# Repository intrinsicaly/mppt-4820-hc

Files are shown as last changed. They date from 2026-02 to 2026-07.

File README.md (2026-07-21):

# MPPT charge controller with HS load switch and CAN

 Development ongoing.

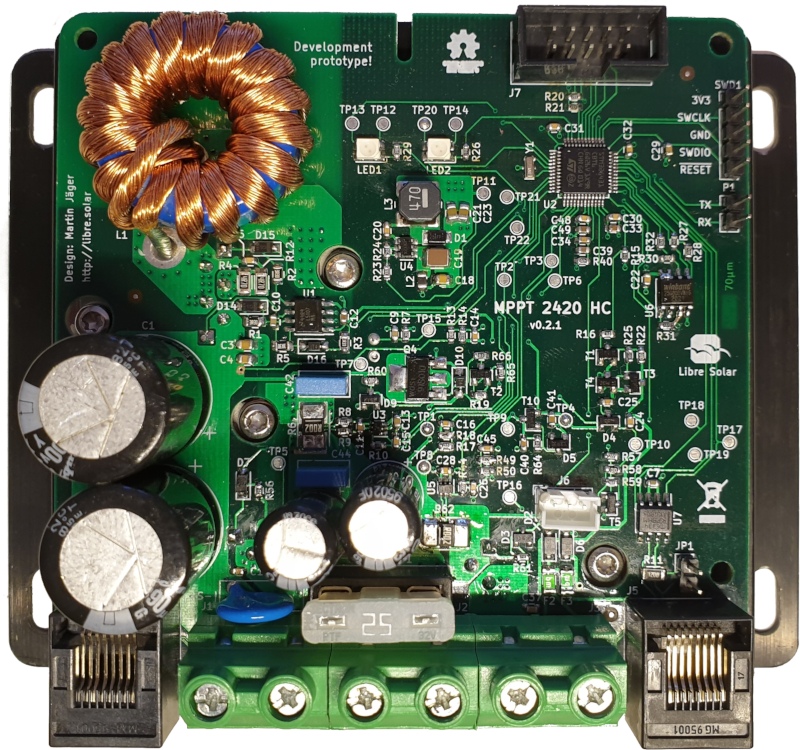
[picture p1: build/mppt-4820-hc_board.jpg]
MPPT 4820 HC


Schematic: [PDF file](build/mppt-4820-hc_schematic.pdf)

Bill of Materials: [CSV file](build/mppt-4820-hc_bom_(hv_supply,can).csv) or [interactive HTML BOM](https://libre.solar/mppt-4820-hc/build/mppt-4820-hc_ibom.html)

Firmware repository: [LibreSolar/charge-controller-firmware](https://github.com/LibreSolar/charge-controller-firmware)

This charge controller design is the replacement for the MPPT 2420 LC. We are also working on an integration of MPPT control algorithms for wind turbines.

## Features

- Solar input terminal
    - 15V to 140V operating range
    - 140V maximum open-circuit input
- Battery output terminal
    - 24V / 48V systems
    - Up to 42A @ 24V mode, up to 21A @ 48V mode
    - Up to 1kW output power
- Load terminal: 20A
- New STM32G431 ARM MCU with advanced digital power conversion features
- Expandable via Olimex Universal Extension Connector (UEXT)
- Two bi-color (red/green) LEDs for status indication. Additional user interface can be included in separate PCB in front panel housing and connected via UEXT
- CAN interface via RJ45 connectors

## Current design baseline

- The 24V/48V, 1kW hardware baseline is documented in `docs/HARDWARE_UPGRADE_1KW.md`.
- Source of truth for electrical design is the KiCad schematics in `kicad/`.
- `build/` outputs (PDF/BOM/render) should be regenerated from current schematics before release or manufacturing decisions.

## Mechanical design

- TO-220 MOSFETs can be screwed to large heat sink at the back
- Plastic cover under development

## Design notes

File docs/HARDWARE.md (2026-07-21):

# MPPT 4820 HC Hardware Documentation

## Overview

The MPPT 4820 HC is a Maximum Power Point Tracking (MPPT) solar charge controller with high current capability. This document describes the hardware design files and project structure.

**Key Specifications (current baseline):**
- Solar Input: 15V to 140V (140V max open-circuit)
- DC/DC Converter: 24V/48V battery charging
- Battery Output: 24V / 48V systems
- Maximum Current: 42A (24V mode), 21A (48V mode)
- Maximum Output Power: 1kW
- Load Output: 20A switching capability
- MCU: STM32G431 ARM Cortex-M4
- Communication: CAN bus via RJ45 connectors
- Expansion: UEXT connector (Olimex Universal Extension)

## Project Status

**Status:** Hardware upgrade baseline defined for 24V/48V operation (see `docs/HARDWARE_UPGRADE_1KW.md`); validation and release harmonization ongoing.

## Directory Structure

```
kicad/
├── mppt-4820-hc.sch          # Top-level schematic (hierarchical)
├── dcdc.sch                   # DC/DC converter stage (Sheet 2)
├── power-supply.sch           # Power supply circuitry (Sheet 3)
├── mcu.sch                    # Microcontroller and peripherals (Sheet 4)
├── load-switch.sch            # Load switching circuit (Sheet 5)
├── can.sch                    # CAN bus interface (Sheet 6)
├── project.lib                # Custom component library
├── project.dcm                # Component documentation
├── mppt-4820-hc-cache.lib     # Cached library components
├── sym-lib-table              # Symbol library table
├── fp-lib-table               # Footprint library table
├── mppt-4820-hc.pro           # KiCad project settings
├── bom.ini                    # Bill of Materials configuration
└── libre-solar.kicad_wks      # Custom worksheet template
```

## Schematic Hierarchy

The design uses a hierarchical structure with 6 sheets:

### Sheet 1: Top Level (mppt-4820-hc.sch)
- Project overview and sheet interconnections
- Top-level block diagram
- Sheet connector definitions

### Sheet 2: DC/DC Converter (dcdc.sch)
**Purpose:** Main power conversion stage

**Key Components:**
- High-side and low-side MOSFETs for 24V/48V, 1kW operation
- Power inductor (high current capability)
- Input/output filtering capacitors
- Current sensing circuitry
- Voltage dividers for monitoring

**Signals:**
- `DCDC_HV+/DCDC_HV-`: High voltage (solar) side
- `DCDC_LV+`: Low voltage (battery) side
- `PWM_HS/PWM_LS`: PWM control signals
- `V_DCDC_H/V_DCDC_L`: Voltage sensing
- `I_DCDC`: Current sensing

### Sheet 3: Power Supply (power-supply.sch)
**Purpose:** Generate low-voltage rails for control circuits

**Features:**
- Buck converter from battery/high-voltage side
- Multiple voltage rails (3.3V, 5V, and gate-driver supply)
- Charge pump for high-side gate drive
- Protection and filtering

### Sheet 4: MCU (mcu.sch)
**Purpose:** Microcontroller and core peripherals

**Key Components:**
- STM32G431 microcontroller
- Crystal oscillator
- EEPROM (24AA01 - 1K I2C)
- Programming header (SWD)
- Reset circuitry
- Decoupling capacitors

**Features:**
- Advanced timer for PWM generation
- Multiple ADC channels for sensing
- I2C for EEPROM communication
- GPIO for control and status

### Sheet 5: Load Switch (load-switch.sch)
**Purpose:** Controllable load output switching

**Features:**
- High-side or low-side switching (20A capability)
- Current sensing on load output
- Protection circuitry
- PWM dimming capability (optional)

### Sheet 6: CAN Bus (can.sch)
**Purpose:** CAN communication interface

**Key Components:**
- TCAN334 CAN transceiver
- RJ45 connectors for CAN bus
- Termination resistor (jumper selectable)
- ESD protection

**Features:**
- Differential CAN signaling
- Bus termination option
- Daisy-chain capability via dual RJ45

## Component Libraries

### Custom Library (project.lib)
Contains project-specific components including:

**Power Components:**
- Power supply symbols (+10V, +12V references)
- Battery symbol

**ICs:**
- STM32F072RBTx (ARM Cortex-M0 - earlier version)
- STM32G431 (current MCU - ARM Cortex-M4)
- 24AA01 (I2C EEPROM)
- AP2210-3.3 (LDO regulator)
- AZ1117 (voltage regulator)
- LMR16030 (buck converter)
- TCAN334 (CAN transceiver)

**Passive Components:**
- Resistors (R), capacitors (C), inductors (L)
- Resistor packs (R_PACK4, R_PACK8)
- Potentiometers

**Semiconductors:**
- Diodes (D, D_Schottky, D_Zener)
- MOSFETs (Q_NMOS)

**Connectors:**
- Generic connectors
- 8P8C (RJ45)
- UEXT connector

### External Libraries

**LibreSolar Footprints:**
- URL: https://github.com/LibreSolar/kicad-footprints
- Custom footprints for LibreSolar projects
- Optimized for manufacturing

## Bill of Materials (BOM)

### BOM Configuration (bom.ini)

**Features:**
- Grouped by component value and footprint
- DNF (Do Not Fit) component filtering
- Multiple configuration support (+can, +hv_supply variants)
- CSV and HTML output formats

**Output Location:** `../build/mppt-4820-hc_bom_(variant).csv`

**Interactive BOM:** Available at `build/mppt-4820-hc_ibom.html`

### Component Sourcing

Key components require specific attention:

1. **MOSFETs:** High-voltage/high-current parts sized for 24V/48V, 1kW operation
2. **Inductor:** High current (50A peak class), low DCR
3. **MCU:** STM32G431 (specific package)
4. **CAN Transceiver:** TCAN334 or compatible

## PCB Design Specifications

### Layer Stack (from mppt-4820-hc.pro)

**4-layer board:**
1. **F.Cu (Top):** Signal and component layer
2. **In1.Cu (GND):** Ground plane
3. **In2.Cu (3V3):** Power plane (3.3V)
4. **B.Cu (Bottom):** Signal and component layer

### Design Rules

**Track Widths:**
- Default: 0.25mm
- Power traces: 0.3mm, 0.4mm, 0.5mm options
- High current: Custom width per trace

**Via Specifications:**
- Minimum diameter: 0.7mm
- Drill: 0.3mm
- Power vias: up to 1.0mm diameter

**Clearances:**
- Minimum track width: 0.2mm
- Minimum hole-to-hole: 0.25mm
- Soldermask clearance: As per manufacturer

**Board Parameters:**
- Thickness: 1.6mm
- Copper layers: 4
- No blind/buried vias

## Manufacturing Files

Generated files in `build/` directory:

```
build/
├── mppt-4820-hc_schematic.pdf     # Schematic documentation
├── mppt-4820-hc_bom_*.csv         # Bill of materials
├── mppt-4820-hc_ibom.html         # Interactive BOM
└── mppt-4820-hc_board.jpg         # Board render
```

> Note: `build/` artifacts are snapshots and may lag behind schematic updates. For design reviews, use the current KiCad source in `kicad/` and regenerate outputs before manufacturing.

## Working with the Project

### Prerequisites

**Required Software:**
- KiCad 5.x or later (project uses v5.1+ features)
- Git (for version control)

**Recommended:**
- KiBoM plugin (for BOM generation)
- InteractiveHtmlBom plugin

### Opening the Project

1. Clone the repository
2. Open KiCad
3. File → Open Project
4. Navigate to `kicad/mppt-4820-hc.pro`

### Library Dependencies

The project uses:
- Standard KiCad libraries
- LibreSolar custom footprints (from GitHub)
- Project-specific library (project.lib)

**Library Setup:**
- Symbol libraries: Defined in `sym-lib-table`
- Footprint libraries: Defined in `fp-lib-table`
- Both use relative paths for portability

### Generating Manufacturing Files

**Gerbers:**
1. Open PCB editor (Pcbnew)
2. File → Plot
3. Select Gerber format
4. Generate drill files

**BOM:**
```bash
# Using KiBoM (if installed)
python3 -m kibom kicad/mppt-4820-hc.xml build/ -c kicad/bom.ini
```

**Assembly Files:**
- Position files: Generated from Pcbnew
- Interactive BOM: Use InteractiveHtmlBom plugin

## Variants and Configurations

The project supports multiple build configurations using the "Config" field:

### Variant: +can
Includes CAN bus components:
- TCAN334 transceiver
- RJ45 connectors
- Termination resistor

### Variant: +hv_supply
High voltage supply option:
- Alternative input filtering
- Extended voltage range components

### Variant: default
Base configuration without optional features

## Firmware Integration

**Firmware Repository:** [LibreSolar/charge-controller-firmware](https://github.com/LibreSolar/charge-controller-firmware)

**Hardware-Firmware Interface:**
- PWM outputs for MOSFET control
- ADC inputs for voltage/current sensing
- I2C for EEPROM
- CAN bus for communication
- GPIO for status LEDs and enable signals

## Revision History

- **v1.0.0** (2026-02-20): 24V/48V hardware baseline updates (1kW design direction)
- Earlier versions documented in git history

## Design Notes

### Critical Circuits

**High-Side Gate Drive:**
- Requires charge pump or bootstrap circuit
- Ensure sufficient gate voltage for full enhancement
- Dead-time control to prevent shoot-through

**Current Sensing:**
- Shunt resistor location and value critical
- Filtering required for ADC accuracy
- Consider temperature effects

**Power Inductor:**
- Selection based on peak current, DCR, and saturation
- Core material affects efficiency
- Physical size constraint

### Safety Considerations

1. **Reverse Polarity Protection:** Verify on input and output
2. **Overcurrent Protection:** Hardware and software limits
3. **Overvoltage Protection:** MOV or TVS diodes
4. **Thermal Management:** Heat sink required for MOSFETs

### Testing Points

Recommended test points (if not already present):
- Solar input voltage
- Battery voltage
- Load voltage
- Inductor current sense
- Gate drive signals
- MCU power rails

## License

This hardware design is licensed under CERN-OHL-W version 2 (weakly reciprocal).

**Copyright © 2020 Libre Solar Technologies GmbH**

See [LICENCE](../LICENCE) file for full license text.

## Contributing

Contributions are welcome! Please see the main project repository for:
- Issue tracking
- Pull request guidelines
- Development discussion

## Support and Documentation

- **Main Repository:** https://github.com/intrinsicaly/mppt-4820-hc
- **Libre Solar Website:** https://libre.solar
- **Community Forum:** (link TBD)
- **Schematic PDF:** [build/mppt-4820-hc_schematic.pdf](../build/mppt-4820-hc_schematic.pdf)

## Related Projects

- **MPPT 2420 HC:** Lower voltage/current variant
- **Charge Controller Firmware:** Compatible firmware
- **LibreSolar BMS:** Battery management integration

---

**Document Version:** 1.0  
**Last Updated:** 2026-02-20  
**Author:** Martin Jäger (original hardware), Documentation team

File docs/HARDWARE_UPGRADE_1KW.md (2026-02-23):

# MPPT 4820 HC — 1 kW Hardware Upgrade Specification

## 1. Overview

This document describes the hardware modifications required to upgrade the MPPT 4820 HC from its
original ~500 W design (20 A inductor, 80 V PV input) to a 1 kW design supporting dual battery
voltage (24 V / 48 V) and a 140 V PV input.

### 1.1 Design Goals

| Goal | Original | Upgraded |
|---|---|---|
| Output power | ~500 W | 1 000 W |
| Battery voltage | 12 V / 24 V | 24 V / 48 V |
| Max PV input voltage | 80 V | 140 V |
| Max inductor current | 20 A | 50 A (peak) |
| Max battery current (24 V) | 20 A | 42 A |
| Max battery current (48 V) | — | 21 A |
| Switching frequency | ~100 kHz | 80 kHz |
| Target efficiency | >93 % | >95 % |
| Ambient temperature | −20 °C to +40 °C | −20 °C to +50 °C |
| Design life | — | 10+ years |

---

## 2. Component Upgrade Specifications

### 2.1 High-Side Power MOSFET — Q1

The high-side switch must block the full PV open-circuit voltage with adequate margin.

| Parameter | Original | Upgraded |
|---|---|---|
| Part number | (100 V NMOS) | **Infineon IPW60R041P6** |
| Package | TO-220 | TO-247 |
| V_DS(max) | 100 V | 650 V |
| R_DS(on) @ 25 °C | — | 41 mΩ |
| I_D (continuous) | — | 38 A |
| Q_g (total) | — | 110 nC |
| t_rr | — | 65 ns |

**Alternatives:**

- STMicroelectronics STW48N60DM2 (600 V, 38 mΩ, TO-247)
- ON Semiconductor FCPF22N60 (600 V, 260 mΩ — only for low-power variant)

**Rationale:** 140 V PV OC × 1.5 safety margin = 210 V minimum; 650 V provides generous margin
for load-dump transients and lightning coupling on PV cable.

---

### 2.2 Low-Side Power MOSFET — Q2

The low-side switch carries the full inductor current and must have ultra-low R_DS(on) to
minimise conduction losses at 42 A.

| Parameter | Original | Upgraded |
|---|---|---|
| Part number | (100 V NMOS) | **Infineon IPT015N10N5** |
| Package | TO-220 | TO-220 |
| V_DS(max) | 100 V | 100 V |
| R_DS(on) @ 25 °C | — | 1.5 mΩ |
| I_D (continuous) | — | 100 A |
| Q_g (total) | — | 91 nC |

**Alternatives:**

- Vishay SiR622DP (100 V, 1.7 mΩ, PowerPAK SO-8)
- Infineon BSC010N04LS (40 V, 1.0 mΩ — only if max battery voltage ≤ 40 V)

**Rationale:** At 42 A the conduction loss is P = I² × R_DS(on) = 42² × 0.0015 = 2.65 W,
acceptable for TO-220 without forced air.

---

### 2.3 Power Inductor — L1

| Parameter | Original | Upgraded |
|---|---|---|
| Part number | — | **Würth Elektronik 7443730470** |
| Inductance | — | 4.7 µH |
| Saturation current | 20 A | 50 A |
| DCR (typical) | — | 2.4 mΩ |
| Core loss @ 80 kHz | — | see §3 |
| Dimensions | — | 22.5 × 22.5 × 19.5 mm |
| Temperature rise (rated) | — | ΔT = 40 °C @ I_sat |

**Alternatives:**

- Coilcraft XAL8080-472 (4.7 µH, 45 A saturation, lower DCR but smaller footprint)
- Bourns SRR1260-4R7Y (4.7 µH, 34 A — marginal; derate to 40 A max if used)

**Selection Criteria:**

```
Ripple current (ΔI_L):
  ΔI_L = (V_in − V_out) × D / (L × f_sw)
       = (140 V − 48 V) × 0.343 / (4.7 µH × 80 kHz)
       = 92 V × 0.343 / 0.376 A
       = 83.9 V / 376 Ω
       ≈ 10.6 A_pp   (25 % of I_peak = 42.5 A) ✓

Peak inductor current:
  I_peak = I_out + ΔI_L / 2 = 42 + 5.3 = 47.3 A < 50 A saturation ✓
```

---

### 2.4 Current Sense Resistor — R_shunt

| Parameter | Original | Upgraded |
|---|---|---|
| Part number | — | **Bourns CRE2512-FZ-R001E-3** |
| Resistance | — | 1 mΩ |
| Power rating | — | 3 W |
| Tolerance | — | ±1 % |
| Temperature coefficient | — | ±75 ppm/°C |
| Package | — | 2512 SMD |

**Alternatives:**

- Vishay WSBS2515 (1 mΩ, 5 W — preferred if PCB copper pour is limited)
- KOA Speer SMB2A-R001 (1 mΩ, 3 W — direct footprint alternative)

**Voltage at full load:**

```
V_shunt = I × R = 42 A × 0.001 Ω = 42 mV
Power  = I² × R = 42² × 0.001    = 1.76 W < 3 W rating ✓
```

---

### 2.5 Input Capacitors — C_in

The input capacitors must withstand the PV open-circuit voltage with appropriate margin.

| Parameter | Original | Upgraded |
|---|---|---|
| Voltage rating | 100 V | **160 V** |
| Capacitance | — | 4 × 100 µF |
| ESR (each) | — | < 50 mΩ |
| Type | Electrolytic | Electrolytic + X7R ceramic |
| Example part | — | Nichicon UHE2C101MED (100 µF, 160 V, Ø16 × 25 mm) |
| Ceramic bypass | — | 2 × 100 nF, 250 V X7R (e.g., Kemet C1210C104KARACTU) |

**Rating check:**

```
V_PV_OC(max) = 140 V
Rated voltage derating @ 70 % = 160 V × 0.70 = 112 V
Operating margin = 112 V / 140 V = 80 % → pass with 160 V rating ✓

For 85 °C-rated caps at 50 °C ambient, lifetime multiplier ≈ 8× per 10 °C drop
→ Long-life (105 °C rated) caps recommended; see §5.
```

---

### 2.6 Output Capacitors — C_out

| Parameter | Original | Upgraded |
|---|---|---|
| Voltage rating | 35 V / 50 V | **63 V** |
| Capacitance | — | 4 × 680 µF |
| ESR (each) | — | < 30 mΩ |
| Type | Electrolytic | Electrolytic (low ESR) |
| Example part | — | Panasonic EEEFK1J681P (680 µF, 63 V, Ø18 × 20 mm) |

**Ripple current check:**

```
I_ripple_cap = ΔI_L / (2√3) = 10.6 / 3.46 ≈ 3.1 A_rms
Rated ripple (Panasonic EEEFK1J681P) = 3.97 A_rms @ 105 °C → ✓
```

---

### 2.7 Gate Driver — U_GD

The gate driver must support the bootstrap rail required for 140 V high-side drive and provide
sufficient peak current to switch 100+ nC gates at 80 kHz.

| Parameter | Original | Upgraded |
|---|---|---|
| Part number | — | **Texas Instruments UCC27712** |
| Supply voltage | — | 10–20 V |
| Bootstrap voltage | — | 150 V (VS pin) |
| Source / sink current | — | 4 A / 4 A |
| Propagation delay | — | 50 ns typ |
| Dead-time (adjustable) | — | via R_DT |
| Package | — | SOIC-8 |

**Alternatives:**

- Silicon Labs Si8271 (isolated, 150 V bootstrap, 4 A) — preferred for improved EMI isolation
- Microchip MCP14628 (100 V bootstrap only — not suitable for 140 V PV)

**Bootstrap capacitor:**

```
C_boot ≥ Q_g(Q1) / ΔV_boot = 110 nC / 0.3 V = 367 nF
Use 470 nF, 200 V X7R ceramic (e.g., Kemet C1206C474KARAC7800)
```

---

### 2.8 Voltage Sensing Dividers

Two resistive dividers are required: one for the PV (high) side and one for the battery (low) side.

#### 2.8.1 PV Voltage Divider (140 V range)

```
Target ADC range: 0–3.3 V for 0–165 V (125 % of 132 V = V_PV_OC @ STC)
Ratio: k = 3.3 / 165 = 0.02
R_top / R_bot = (1 − k) / k = 49

Use: R_top = 1 MΩ (2 × 499 kΩ in series for reliability)
     R_bot = 20.0 kΩ (1 % tolerance)
Ratio check: 1 000 / 20 = 50 → V_ADC = 3.3 × (20/1020) × 165 = 3.26 V ✓
Power (R_top @ 140 V) = 140² / 1 000 000 = 19.6 mW → use 0603 0.1 W ✓
```

| Component | Value | Package | Rating |
|---|---|---|---|
| R_PV_top1 | 499 kΩ, 1 % | 0603 | 100 mW |
| R_PV_top2 | 499 kΩ, 1 % | 0603 | 100 mW |
| R_PV_bot  | 20.0 kΩ, 1 % | 0603 | 100 mW |
| C_PV_filt | 10 nF, 200 V | 0603 | X7R |

#### 2.8.2 Battery Voltage Divider (58 V range)

```
Target ADC range: 0–3.3 V for 0–60 V
Ratio: k = 3.3 / 60 = 0.055
R_top / R_bot = (1 − k) / k = 17.18 → use 16.9 (standard ratio)

Use: R_top = 169 kΩ (standard E96)
     R_bot = 10.0 kΩ
Ratio check: 169 / 10 = 16.9 → V_ADC @ 58 V = 58 × 10 / 179 = 3.24 V ✓
```

| Component | Value | Package | Rating |
|---|---|---|---|
| R_BAT_top | 169 kΩ, 1 % | 0603 | 100 mW |
| R_BAT_bot | 10.0 kΩ, 1 % | 0603 | 100 mW |
| C_BAT_filt | 10 nF, 50 V | 0603 | X7R |

---

### 2.9 Current Sense Amplifier

The 42 mV full-scale shunt signal must be amplified to match the ADC input range.

```
Required gain: G = 3.3 V / 0.042 V ≈ 78.6 V/V
Use G = 78 V/V: R_gain = 10 kΩ, R_fb = 780 kΩ (nearest standard: 787 kΩ)
Actual gain: 787 / 10 = 78.7 V/V → V_ADC @ 42 A = 42 × 0.001 × 78.7 = 3.305 V ✓
```

| Parameter | Value |
|---|---|
| Recommended IC | Texas Instruments INA240A3 (80 V common-mode, 20 V/V fixed — requires external stage) |
| Alternative | Analog Devices AD8418A (70 V CM, adjustable gain, SOT-23-8) |
| Gain (set externally) | 78 V/V |
| R_gain | 10 kΩ, 1 % (0402) |
| R_feedback | 787 kΩ, 1 % (0402) |
| Bandwidth | > 100 kHz |
| Common-mode range | 0–140 V |

---

### 2.10 Protection Components

#### 2.10.1 PV Input TVS Diode

| Parameter | Value |
|---|---|
| Part number | Littelfuse SMBJ150A |
| Standoff voltage | 150 V |
| Clamping voltage | 243 V @ 10 A |
| Peak pulse power | 600 W |
| Package | DO-214AA (SMB) |

#### 2.10.2 Gate Drive Bootstrap TVS

| Parameter | Value |
|---|---|
| Part number | Vishay MMSZ5248B |
| Zener voltage | 18 V |
| Purpose | Clamp V_GS of Q1 to 20 V max |
| Package | SOD-123 |

#### 2.10.3 Battery Output TVS

| Parameter | Value |
|---|---|
| Part number | Littelfuse SMBJ58A |
| Standoff voltage | 58 V |
| Clamping voltage | 93.6 V @ 10 A |
| Package | DO-214AA (SMB) |

---

### 2.11 Power Supply Modifications

The auxiliary power supply (Sheet 3 in the schematic hierarchy) must be modified to:

1. **Accept 24 V–58 V battery input** (previously 10–32 V) — verify LMR16006 or replace with a
   part rated for 60 V input such as the **Texas Instruments LMR16030** (60 V, 3 A, SIMPLE
   SWITCHER).
2. **Maintain 5 V @ 500 mA** rail for the gate driver.
3. **Add 15 V rail** for UCC27712 V_DD (use LM7815 or TI TLV62568 buck regulated from 5 V).

| Rail | Original | Upgraded |
|---|---|---|
| V_IN range | 10–32 V | 24–58 V |
| 3.3 V (MCU) | ✓ keep | ✓ keep |
| 5 V (aux) | ✓ keep | ✓ keep |
| 15 V (gate driver) | — | **add** |
| Buck IC | LMR16006 (42 V) | **LMR16030 (60 V)** |

---

## 3. Thermal Management

### 3.1 Power Loss Calculations

All calculations at maximum load: P_out = 1 008 W (42 A × 24 V), f_sw = 80 kHz, T_amb = 50 °C.

#### Q1 — High-Side MOSFET

```
Duty cycle @ 48 V battery, 140 V PV:   D = V_out / V_in = 48 / 140 = 0.343
Conduction loss: P_cond = I²_rms × R_DS(on)
  I_rms(Q1) = I_out × √D = 21 A × √0.343 = 12.3 A
  P_cond    = 12.3² × 0.041 = 6.2 W

Switching loss (approximate):
  P_sw = 0.5 × V_DS × I_D × (t_r + t_f) × f_sw
       = 0.5 × 140 × 21 × (25 ns + 30 ns) × 80 000
       = 0.5 × 140 × 21 × 55e-9 × 80 000
       ≈ 6.5 W

Total Q1 loss: P_Q1 = 6.2 + 6.5 = 12.7 W

Junction temperature:
  θ_JC (IPW60R041P6) = 0.42 °C/W
  θ_CS  (TO-247, insulated pad) ≈ 0.5 °C/W
  θ_SA  (target) = (175 − 50) / 12.7 − 0.42 − 0.5 = 9.9 − 0.92 ≈ 9.0 °C/W
  Use heatsink: R_SA ≤ 9 °C/W

  T_J = T_amb + P × (θ_JC + θ_CS + θ_SA)
      = 50 + 12.7 × (0.42 + 0.5 + 5.0)       [example: R_SA = 5 °C/W]
      = 50 + 12.7 × 5.92
      = 50 + 75 ≈ 125 °C   (margin to 175 °C = 50 °C) ✓

Conservative worst-case (shared heatsink, R_SA = 7 °C/W):
  T_J = 50 + 12.7 × (0.42 + 0.5 + 7.0) = 50 + 101 = 151 °C → still < 175 °C ✓
  Margin = 175 − 151 = 24 °C ✓
```

#### Q2 — Low-Side MOSFET

```
Duty cycle complement: D' = 1 − D = 1 − 0.343 = 0.657
I_rms(Q2) = I_out × √D' = 42 A × √0.657 = 34.0 A
P_cond    = 34.0² × 0.0015 = 1.73 W

Switching loss (body diode reverse recovery):
  P_sw_Q2 = Q_rr × V_DS × f_sw = 45e-9 × 100 × 80 000 = 0.36 W

Total Q2 loss: P_Q2 = 1.73 + 0.36 = 2.09 W

θ_JC (IPT015N10N5) = 0.5 °C/W
T_J = 50 + 2.09 × (0.5 + 0.5 + 5.0) = 50 + 12.5 = 62.5 °C ✓
Margin to 175 °C = 112 °C ✓
```

#### L1 — Power Inductor

```
DCR loss:   P_DCR = I²_rms × DCR = 35 A² × 0.0024 = 2.94 W
            (I_rms ≈ 35 A for 50 % duty cycle, worst case)

Core loss (estimated from datasheet curves at 80 kHz, ΔB ~ 50 mT):
  P_core ≈ 5 W

Total inductor loss: P_L = 2.94 + 5 = ~8 W

Temperature rise:
  ΔT_L = P_L × R_th(winding-to-ambient)
  Würth 7443730470 rated ΔT = 40 °C @ P_rated
  At 8 W with natural convection: ΔT ≈ 40 °C
  T_L = 50 + 40 = 90 °C < 155 °C (core rated max) ✓
  Margin = 65 °C ✓
```

#### Shunt Resistor

```
P_shunt = I² × R = 42² × 0.001 = 1.76 W
Bourns CRE2512 rated 3 W → derating @ 50 °C: 3 × (155 − 50) / (155 − 25) = 2.42 W
1.76 W < 2.42 W ✓
```

### 3.2 Total Efficiency

```
Total losses:
  P_Q1      = 12.7 W
  P_Q2      =  2.1 W
  P_L       =  8.0 W
  P_shunt   =  1.8 W
  P_gate    =  1.5 W  (Q_g_total × V_GS × f_sw × 2)
  P_control =  2.0 W  (aux supply, MCU, etc.)
  ─────────────────
  P_loss    = 28.1 W  (48 V output mode)

η = P_out / (P_out + P_loss) = 1008 / (1008 + 28.1) = 97.3 %   (48 V mode) ✓

24 V mode (worst case, higher duty cycle):
  Additional switching losses on Q1 ≈ 9 W (higher D)
  P_loss ≈ 46 W
  η = 1008 / (1008 + 46) = 95.6 %                               (24 V mode) ✓
```

---

## 4. PCB Layout Requirements

### 4.1 Power Trace Widths

Use IPC-2221 (external trace, 30 °C temperature rise) as the baseline:

| Net | Current | Min Width (1 oz) | Min Width (2 oz) | Recommended |
|-----|---|---|---|---|
| PV+ / PV− | 42 A | 22 mm | 11 mm | **Pour + 2 oz copper** |
| Inductor loop | 50 A (peak) | 26 mm | 13 mm | **Pour + 2 oz copper** |
| Battery+ / Battery− | 42 A | 22 mm | 11 mm | **Pour + 2 oz copper** |
| Gate drive | 0.5 A | 0.3 mm | 0.2 mm | 0.5 mm |
| Sense signals | < 10 mA | 0.2 mm | 0.2 mm | 0.3 mm |

**Recommendation:** Use 2 oz (70 µm) copper on the power layers. Add thermal relief vias to
transfer heat from surface pads to internal copper planes.

### 4.2 Voltage Clearances

IEC 60664-1 (overvoltage category II, pollution degree 2):

| Voltage | Min PCB Clearance | Min Creepage |
|---|---|---|
| 140 V (PV) | 1.0 mm | 2.0 mm |
| 48 V (battery) | 0.5 mm | 1.0 mm |
| 15 V (gate supply) | 0.3 mm | 0.6 mm |

### 4.3 Thermal Via Arrays

Place thermal via arrays (0.3 mm drill, 0.6 mm pad) under:

- Q2 source pad: minimum 16 vias in 4 × 4 grid
- Shunt resistor pads: minimum 9 vias per pad
- Inductor footprint: 4 corner vias to improve heat spreading

### 4.4 Gate Drive Loop Minimisation

- Route gate and source of Q1 and Q2 as tightly coupled differential pairs
- Keep gate resistors (R_G) within 10 mm of MOSFET gate pin
- Separate gate-drive return from power-stage return; join only at the MOSFET source pad

### 4.5 Copper Weight

| Layer | Original | Upgraded |
|---|---|---|
| F.Cu (Top) | 1 oz | **2 oz** |
| In1.Cu (GND) | 1 oz | **2 oz** |
| In2.Cu (PWR) | 1 oz | **2 oz** |
| B.Cu (Bottom) | 1 oz | **2 oz** |

---

## 5. Design Life Analysis

### 5.1 Capacitor Lifetime (Electrolytic)

Electrolytic capacitor lifetime follows the Arrhenius model:

```
L = L_0 × 2^((T_rated − T_op) / 10)

Nichicon UHE2C101MED (105 °C rated, L_0 = 5 000 h):
  T_op = T_amb + ΔT_ripple = 50 + 10 = 60 °C  (estimated ripple heating)
  L = 5 000 × 2^((105 − 60) / 10)
    = 5 000 × 2^4.5
    = 5 000 × 22.6
    = 113 000 h ≈ 12.9 years (continuous operation) ✓

For typical solar installation (6 h/day operation):
  Effective life = 113 000 / 6 ≈ 18 800 days ≈ 51 years ✓
```

### 5.2 MOSFET Gate Oxide Lifetime

Gate oxide stress is proportional to V_GS. At V_GS = 15 V and T_J < 150 °C, both devices are
within manufacturer-specified operating limits for 100 000+ hours.

### 5.3 Solder Joint Fatigue (Thermal Cycling)

For components subject to power cycling (MOSFETs, shunt):

- Use leaded or SAC305 solder on TO-220/TO-247 packages
- Apply thermal interface material (T_IM) with sufficient elasticity (e.g., Bergquist GP1500)
- Expected cycles to failure (Coffin-Manson): > 10⁵ cycles at ΔT = 30 °C → > 10 years @ 30 cycles/day

---

## 6. Summary of Upgrades

| Ref | Component | Original Spec | Upgraded Spec | Part Number |
|-----|---|---|---|---|
| Q1 | High-side MOSFET | 100 V, TO-220 | **650 V, 41 mΩ, TO-247** | Infineon IPW60R041P6 |
| Q2 | Low-side MOSFET | 100 V, TO-220 | **100 V, 1.5 mΩ, TO-220** | Infineon IPT015N10N5 |
| L1 | Power inductor | 20 A, µH TBD | **4.7 µH, 50 A, 2.4 mΩ DCR** | Würth 7443730470 |
| R_shunt | Current shunt | — | **1 mΩ, 3 W, 2512** | Bourns CRE2512-FZ-R001E-3 |
| C_in | Input capacitors | 100 V | **160 V, 4 × 100 µF** | Nichicon UHE2C101MED |
| C_out | Output capacitors | 35–50 V | **63 V, 4 × 680 µF** | Panasonic EEEFK1J681P |
| U_GD | Gate driver | — | **UCC27712 (150 V bootstrap)** | Texas Instruments |
| R_PV | PV voltage divider | 80 V range | **140 V range (1 MΩ / 20 kΩ)** | 1 % SMD |
| R_BAT | Battery divider | 32 V range | **58 V range (169 kΩ / 10 kΩ)** | 1 % SMD |
| U_CSA | Current sense amp | — | **INA240A3 + gain stage** | Texas Instruments |
| D_TVS1 | PV input TVS | — | **150 V, 600 W** | Littelfuse SMBJ150A |
| U_PS | Aux power supply IC | LMR16006 (42 V) | **LMR16030 (60 V)** | Texas Instruments |
| PCB | Copper weight | 1 oz | **2 oz all layers** | — |

---

## 7. Cost Impact Estimate

Estimates based on 10-unit prototype pricing (Mouser/Digi-Key, 2025):

| Item | Original BOM cost (est.) | Incremental cost | Notes |
|---|---|---|---|
| Q1 (IPW60R041P6) | — | +$4.50 | vs. generic 100 V FET |
| Q2 (IPT015N10N5) | — | +$3.00 | lower R_DS(on) |
| L1 (Würth 7443730470) | — | +$8.00 | vs. 20 A inductor |
| R_shunt (Bourns CRE2512) | — | +$0.80 | precision 1 mΩ |
| C_in (4 × 160 V) | — | +$6.00 | vs. 100 V caps |
| C_out (4 × 63 V) | — | +$4.50 | vs. 35 V caps |
| Gate driver (UCC27712) | — | +$2.50 | new component |
| Current sense amp | — | +$3.50 | new component |
| TVS diodes | — | +$1.50 | new components |
| Aux supply IC upgrade | — | +$1.00 | LMR16030 vs. LMR16006 |
| PCB 2 oz copper surcharge | — | +$15.00 | per prototype panel |
| **Total incremental cost** | | **≈ +$50.80** | per unit (prototype qty) |
| **Estimated production cost** | | **≈ +$25–35** | at 100+ units |

---

## 8. Performance Specifications

| Parameter | 24 V Mode | 48 V Mode | Unit |
|---|---|---|---|
| PV input voltage range | 15–140 | 15–140 | V |
| PV input voltage (max open-circuit) | 140 | 140 | V |
| Battery voltage range | 22–29 | 44–58 | V |
| Max output current | 42 | 21 | A |
| Max output power | 1 008 | 1 008 | W |
| Switching frequency | 80 | 80 | kHz |
| Peak efficiency | 97.3 | 97.3 | % |
| Efficiency @ full load, 50 °C | 95.6 | 97.3 | % |
| Standby power consumption | < 1 | < 1 | W |
| T_J(Q1) @ full load, 50 °C amb. | 143 | 125 | °C |
| T_J(Q2) @ full load, 50 °C amb. | 68 | 63 | °C |
| T_inductor @ full load, 50 °C amb. | 90 | 85 | °C |
| Ambient operating range | −20 to +50 | −20 to +50 | °C |
| Altitude (derating ≥ 2 000 m) | — | — | m |
| Design life (target) | 10+ | 10+ | years |

---

## Appendix A: Revision History

| Version | Date | Author | Changes |
|---|---|---|---|
| 1.0 | 2026-02-23 | Hardware team | Initial release |

---

**Document Version:** 1.0  
**Last Updated:** 2026-02-23  
**Status:** Draft — pending design review

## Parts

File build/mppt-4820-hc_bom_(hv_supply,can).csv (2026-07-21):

Component | References | Value | Footprint | Description | Quantity Per PCB | Manufacturer | PartNumber | Remarks | Config
0 | NOTE | LEGACY_SNAPSHOT | NA | This BOM snapshot may be stale. Regenerate from current KiCad schematics before purchasing/manufacturing. | 1
1 | C11 C15 | 1nF | C_0603_1608 | Unpolarized capacitor | 2 | any
2 | C6 | 2.2nF | C_0603_1608 | Unpolarized capacitor | 1 | any |  | 100V, C0G
3 | C8 C14 C16 C17 C25 C26 C34 C37 C45 | 10nF | C_0603_1608 | Unpolarized capacitor | 9 | any |  | 100V, X7R
4 | C7 C9 C10 C13 C20 C22 C24 C28 C29 C30 C31 C32 C48 | 100nF | C_0603_1608 | Unpolarized capacitor | 13 | any |  |  | +can
5 | C4 | 100nF | C_0805_2012 | Unpolarized capacitor | 1 | any |  | 100V, X7S
6 | C3 C18 | 1µF | C_0805_2012 | Unpolarized capacitor | 2 | any |  | 100V, X7S
7 | C40 | 1µF | C_0603_1608 | Unpolarized capacitor | 1 | Yageo | CC0805KKX7R9BB105 | 50V, X7R
8 | C21 C23 | 10µF | C_0805_2012 | Unpolarized capacitor | 2 | Murata | GRM21BR61E106KA73L | 25V, X5R
9 | C42 C44 | 0.22µF | C_Rect_L7.2mm_W3.5mm_P5.00mm_FKS2_FKP2_MKS2_MKP2 | Unpolarized capacitor | 2 | EPCOS / TDK | B32529C224J | Alternative: Kemet MMK5224K63J01L16.5TA18
10 | C12 C33 C39 C49 | 2.2µF | C_0603_1608 | Unpolarized capacitor | 4 | any |  | 25V, X5R
11 | C19 | 4.7µF | C_1210_3225 | Unpolarized capacitor | 1 | Murata | GRJ32DC72A475KE11L | 100V, X7S
12 | C41 | 4.7µF | C_0603_1608 | Unpolarized capacitor | 1 | Wurth Electronics | 885012107018 | 25V, X5R
13 | C1 C2 | 560µF | CP_Radial_D18.0mm_P7.50mm | Polarized capacitor | 2 | United Chemi-Con | EKZN101ELL561MM25S | 100V, 2.75A, 18x25
14 | C5 C27 | 680µF | CP_Radial_D18.0mm_P7.50mm | Polarized capacitor | 2 | Panasonic | EEEFK1J681P | 63V, 3.97A, 18x20
15 | D3 D5 | 12V | D_SOT-23_ANK | Diode zener | 2 | ON Semiconductor | SZBZX84C12LT3G | Alternative: Diodes Inc. BZX84C12-7-F
16 | D10 D16 | 1N4148 | D_SOD-123 | Diode | 2 | Diodes Inc. | 1N4148W-7-F
17 | D9 | 47V | D_SOT-23_ANK | Diode zener | 1 | ON Semiconductor | SZBZX84C47LT1G | Alternative: Diodes Inc. BZX84C47-7-F | +hv_supply
18 | D4 | BAS70-04 | SOT-23 | 40V 0.2A Dual Small Signal Schottky Diodes | 1 | ON Semiconductor | BAS70-04LT1G
19 | D2 D6 | NRVTS260ESFT1G | D_SOD-123 | Schottky diode | 2 | On Semiconductor | NRVTS260ESFT1G | Alternative: Nexperia PMEG6020ER,115 | +can
20 | D7 D14 D15 | SS14FL | D_SOD-123 | Diode Schottky | 3 | ON Semiconductor | SS14FL | Alternative: Nexperia PMEG4010EGWX
21 | D1 | SS16FP | D_PowerDI-123 | Diode Schottky | 1 | Diodes Inc. | SS16FP | Alternative: DFLS160-7
22 | F1 | 25A | NULL | Fuse (plug-in) | 1 | Littelfuse | 0287025.PXCN
23 | F2 F3 | 500mA | Fuse_1206_3216Metric | Resettable fuse, polymeric positive temperature coefficient, small symbol | 2 | Bel Fuse | 0ZCJ0050AF2E |  | +can
24 | J4 J5 | 8P8C | RJ45_8P8C | RJ connector, 8P8C (8 positions 8 connected), RJ31/RJ32/RJ33/RJ34/RJ35/RJ41/RJ45/RJ49/RJ61 | 2 | Amphenol FCI | 54602-908LF |  | +can
25 | J6 | JST PH | JST_PH_B3B-PH-K_1x03_P2.00mm_Vertical | Generic connector, single row, 01x03, script generated (kicad-library-utils/schlib/autogen/connector/) | 1 | JST | PH B3B-PH-K 1x3, pitch 2.0mm | LS.pwr
26 | J1 J2 J3 | MKDS 5/ 2-9,5 | Phoenix_Contact_MKDS_5-2-9,5 |  | 3 | Phoenix Contact | 1714971 | Alternative: DECA MB910-952M
27 | J7 | UEXT | Box_Header_2x05x2.54mm_Straight | Olimex UEXT connector (2x5 box header) | 1 | any | Box header 2x5, 2.54mm pitch
28 | JP1 | Jumper_NC_Small | PinHeader_1x02_P2.54mm_Vertical | Jumper normally close | 1 |  |  |  | +can
29 | L2 | 4.7µH | L_0805_2012Metric | Inductor, small symbol | 1 | Murata | LQM21PN4R7NGRD
30 | L3 | 47µH | Bourns_SRN6045TA | Inductor, small symbol | 1 | Tayo Yuden | NR6045T470M | Alternative: Bourns SRR6045TA-470Y
31 | L1 | 4.7µH | Inductor_Wuerth_7443730470 | Inductor | 1 | Würth Elektronik | 7443730470 | 50A saturation, 2.4mΩ DCR
32 | LED1 LED2 | LED_Dual_PLCC4 | LED_Avago_PLCC4_3.2x2.8mm_CW | Dual LED, cathodes on pins 1 and 3 | 2 | Lite-On | LTST-E682KRKGWT | Alternative: Vishay VLMKG3400-GS08
33 | P1 | CONN_01X02 | PinHeader_1x02_P2.54mm_Vertical | Generic connector, single row, 01x02, script generated (kicad-library-utils/schlib/autogen/connector/) | 1 | any | Pin header 1x5, 2.54mm pitch
34 | Q4 | BUK98180-100A | SOT-223-3_TabPin2 | N-MOSFET transistor, gate/drain/source | 1 | Nexperia | BUK98180-100A/CUX | Alternative: Fairchild FQT7N10LTF | +hv_supply
35 | Q1 Q2 Q3 Q7 | MIXED (see schematic) | Mixed footprints | N-MOSFET transistor, gate/drain/source | 4 | Mixed | See schematic | Q1=IPW60R041P6, Q2=IPT015N10N5, Q3/Q7=IPA045N10N3G
36 | R6 R62 | MIXED (1m/2m) | R_Bourns_CRE2512 | Resistor | 2 | Bourns | See schematic | R6=CRE2512-FZ-R001E-3, R62=CRE2512-FZ-R002E-3
37 | R1 R2 R3 R5 | 3R3 | R_0805_2012 | Resistor | 4 | Yageo | RC0805FR-073R3L
38 | R4 R12 | 4R7 | R_1206_3216 | Resistor | 2 | Yageo | RC1206FR-074R7L
39 | R8 R9 | 10R | R_0603_1608 | Resistor | 2 | any |  | 1%
40 | R27 R28 R32 R40 | 47R | R_0603_1608 | Resistor | 4 | any |  | 1%
41 | R11 | 120R | R_1206_3216 | Resistor | 1 | any |  | 1%
42 | R10 R25 R26 R29 R66 | 1k | R_0603_1608 | Resistor | 5 | any |  | 1% | +hv_supply
43 | R14 R20 R21 R31 R44 R57 | 2.2k | R_0603_1608 | Resistor | 6 | any |  | 1%
44 | R18 | 5.6k | R_0603_1608 | Resistor | 1 | any |  | 1%
45 | R50 | 8.2k | C_0603_1608 | Resistor | 1 | any |  | 1%
46 | R7 R16 R19 R24 R49 R59 R64 | 10k | R_0603_1608 | Resistor | 7 | any |  | 1% | +hv_supply
47 | R23 | 33k | R_0603_1608 | Resistor | 1 | any |  | 1%
48 | R13 R17 R22 R30 R58 R60 R65 | 100k | R_0603_1608 | Resistor | 7 | any |  | 1% | +hv_supply
49 | R15 R56 R61 | 1M | R_0603_1608 | Resistor | 3 | any |  | 1%
50 | RT1 | 10k | C_Disc_D3.8mm_W2.6mm_P2.50mm | Temperature dependent resistor, negative temperature coefficient | 1 | TDK | NTCG163JF103FT1S
51 | RV2 | 82V | RV_Disc_D12mm_W4.3mm_P7.5mm | Voltage dependent resistor | 1 | Bourns | MOV-10D820K
52 | SWD1 | ST_Nucleo_SWD | PinHeader_1x05_P2.54mm_Vertical | STM32 Nucleo Board SWD connector (5 pins w/o SWO) | 1 | any | Pin header 1x5, 2.54mm pitch
53 | T1 T2 T3 T5 T10 | BC846B | SOT-23 | 0.1A Ic, 65V Vce, NPN Transistor, SOT-23 | 5 | ON Semiconductor | BC846BLT1G |  | +hv_supply
54 | T4 | BC856B | SOT-23 | 0.1A Ic, 65V Vce, PNP Transistor, SOT-23 | 1 | ON Semiconductor | BC856BLT1G
55 | U3 U5 | MIXED | SC-70-6 / SC-70-5 | Current-sense amplifiers | 2 | Texas Instruments | See schematic | U3=INA240A3DCNR, U5=INA186A1IDCKR
56 | U1 | UCC27712 | SOIC-8_3.9x4.9mm_Pitch1.27mm | High-side/low-side gate driver | 1 | Texas Instruments | UCC27712DR
57 | U4 | LMR16030X | SOT-23-6 | SIMPLE SWITCHER® 4V to 60V, 600mA Step-Down Regulator with Low Iq | 1 | Texas Instruments | LMR16030XDDCR
58 | U2 | STM32G431CBTx | LQFP-48_7x7mm_P0.5mm | ARM Cortex-M4 MCU, 128KB flash, 22KB RAM, 170MHz, 1.71-3.6V, 66 GPIO, LQFP-48 | 1 | ST Microelectronics | STM32G431CBT6
59 | U7 | TCAN334 | SOIC-8_3.9x4.9mm_Pitch1.27mm | High-Speed CAN Transceiver, 1Mbps, 3.3V supply, low power standby mode, shutdown mode, SOT-23-8/SOIC-8 | 1 | Texas Instruments | TCAN334DR |  | +can
60 | U6 | W25Q80DVS | SOIC-8_3.9x4.9mm_Pitch1.27mm | 128Mb Serial Flash Memory, Standard/Dual/Quad SPI, SOIC-8 | 1 | Winbond | W25Q80DVSNIG
61 | XF1 | Fuse_Holder | Keystone-Fuse-3557-2 | Fuse holder | 1 | Keystone | 3557-2
62 | Y1 | 8MHz | Resonator_Murata_CSTNE | Two pin crystal | 1 | Murata | CSTNE8M00GH5C000R0 | 0.07% | +can

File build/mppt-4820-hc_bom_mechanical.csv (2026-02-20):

Component | Description | Material | Quantity Per PCB | Manufacturer | PartNumber | Remarks
1 | Screws for MOSFETs, M3x10 | A2 stainless steel | 4 | any
2 | Self-retaining spacer, D2.5mm, H4.5mm | Nylon 66, natural | 2 | Würth Elektronik | 702916000
3 | Thermal pad |  | 5 | any
4 | Glue for inductor |  | 1 | any
5 | Heat sink | Aluminum | 1 | Libre Solar | 10001

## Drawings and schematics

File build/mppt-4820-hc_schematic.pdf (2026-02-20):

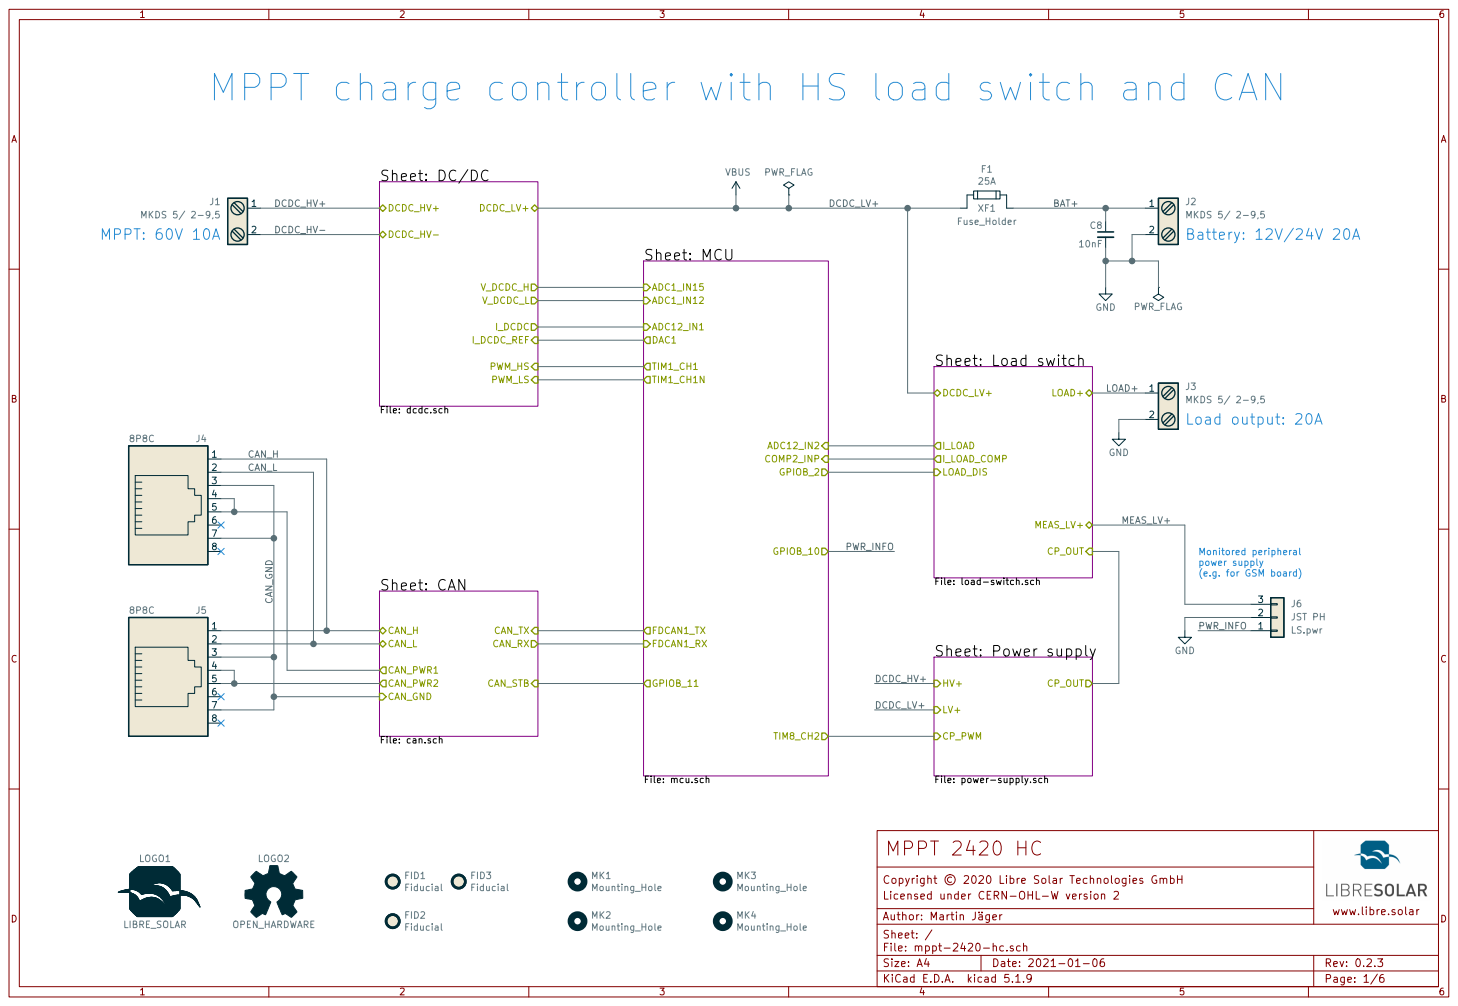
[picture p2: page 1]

File: load-switch.sch

LS.pwr FID1 Fiducial FID2 Fiducial

File: power-supply.sch

File: mppt-2420-hc.sch Sheet: / Copyright © 2020 Libre Solar Technologies GmbH

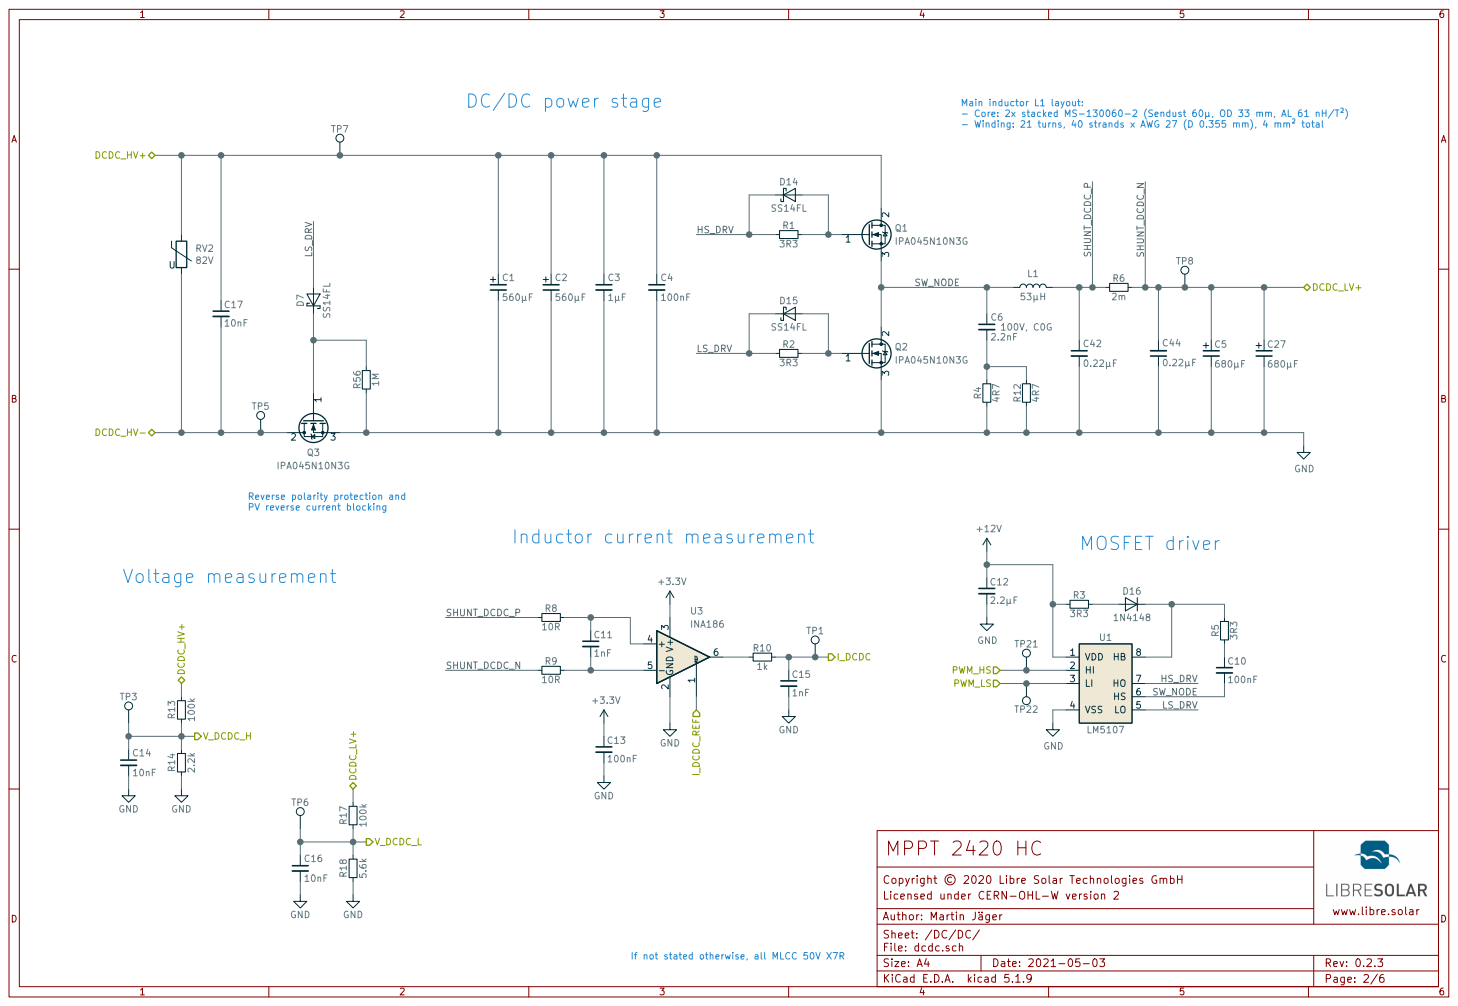
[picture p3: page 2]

DC/DC power stage

- Core: 2x stacked MS-130060-2 (Sendust 60µ, OD 33 mm, AL 61 nH/T²)
- Winding: 21 turns, 40 strands x AWG 27 (D 0.355 mm), 4 mm² total

Reverse polarity protection and
PV reverse current blocking

File: dcdc.sch Sheet: /DC/DC/ Copyright © 2020 Libre Solar Technologies GmbH

If not stated otherwise, all MLCC 50V X7R

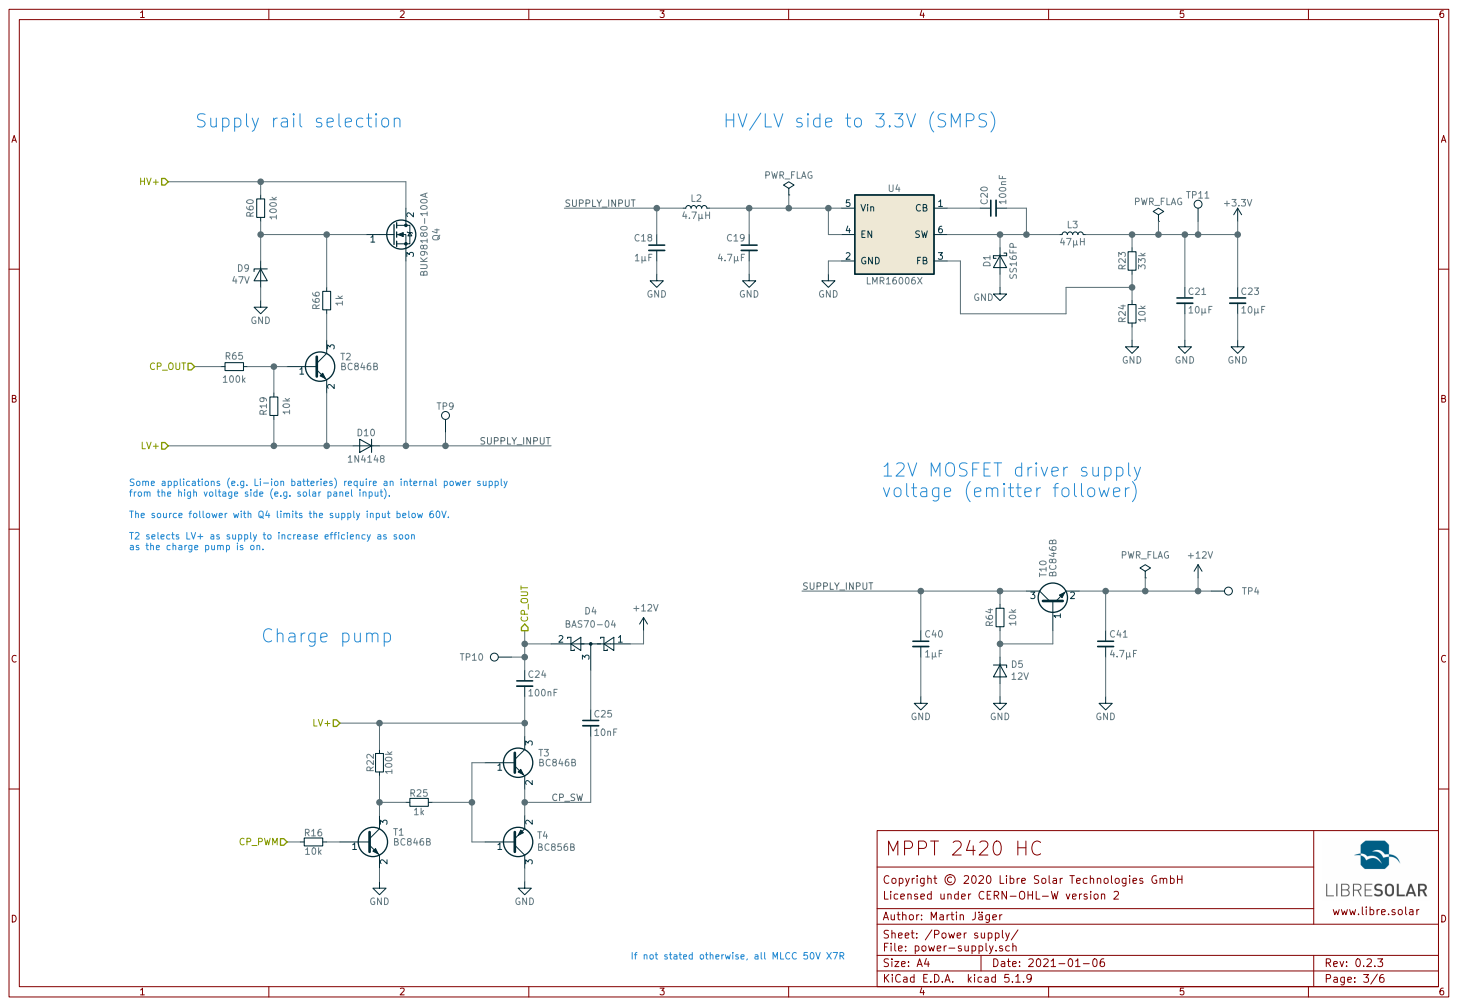
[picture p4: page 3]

HV/LV side to 3.3V (SMPS)

Some applications (e.g. Li-ion batteries) require an internal power supply
from the high voltage side (e.g. solar panel input).

The source follower with Q4 limits the supply input below 60V.

T2 selects LV+ as supply to increase efficiency as soon
as the charge pump is on.

If not stated otherwise, all MLCC 50V X7R Charge pump

Copyright © 2020 Libre Solar Technologies GmbH

Sheet: /Power supply/
File: power-supply.sch

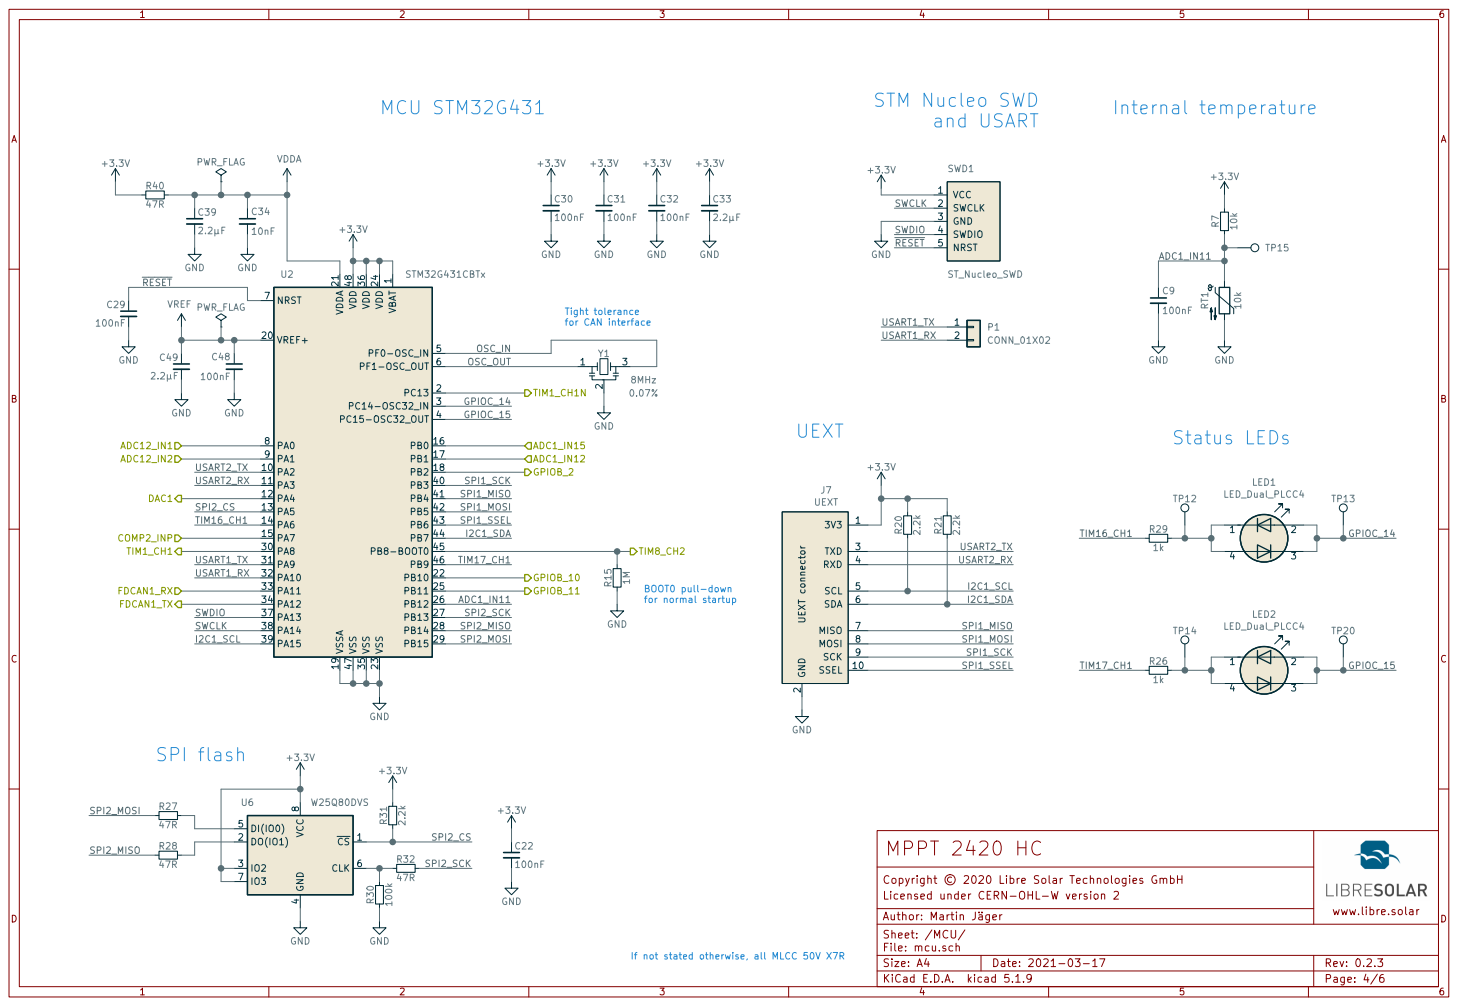
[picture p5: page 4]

If not stated otherwise, all MLCC 50V X7RUEXT

1 PA2 10 PA3 11 PA4 12 PA5 13 PA6 14 PA7 15 PB0 16 PB1 17 PB2 18 VSSA 19 PC13 2 VREF+ 20 VDDA 21 PB10 22 VSS 23 VDD 24 PB11 25 PB12 26 PB13 27 PB14 28 PB15 29 PC14-OSC32_IN 3 PA8 30 PA9 31 PA10 32 PA11 33 PA12 34 VSS 35 VDD 36 PA13 37 PA14 38 PA15 39 PC15-OSC32_OUT 4 PB3 40 PB4 41 PB5 42 PB6 43 PB7 44 PB8-BOOT0 45 PB9 46 VSS 47 VDD 48 PF0-OSC_IN 5 PF1-OSC_OUT 6 NRST 7 PA0 8 PA1 9 U2 STM32G431CBTx C39

for CAN interface SPI flash

2 TXD 3 SCL 5 SDA 6 MISO 7 MOSI 8 SCK 9

File: mcu.sch Sheet: /MCU/ Copyright © 2020 Libre Solar Technologies GmbH

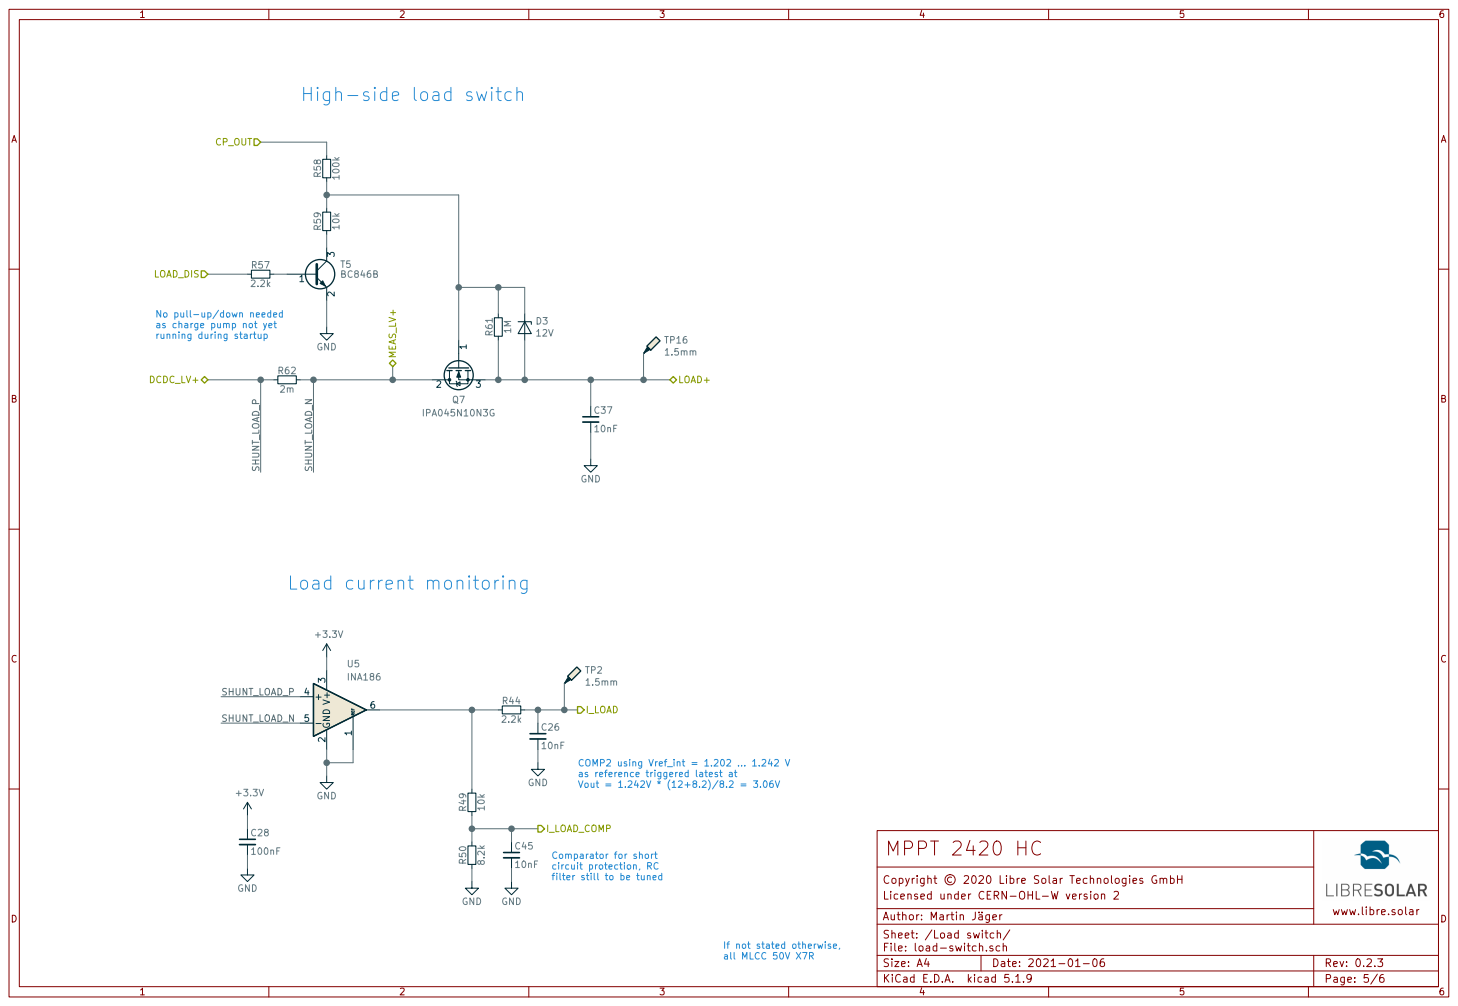
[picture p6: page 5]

No pull-up/down needed
as charge pump not yet
running during startup

COMP2 using Vref_int = 1.202 ... 1.242 V
as reference triggered latest at
Vout = 1.242V * (12+8.2)/8.2 = 3.06V

Comparator for short
circuit protection, RC
filter still to be tuned

File: load-switch.sch Sheet: /Load switch/ Copyright © 2020 Libre Solar Technologies GmbH

www.libre.solar

Licensed under CERN-OHL-W version 2 Author: Martin Jäger

If not stated otherwise, all MLCC 50V X7R

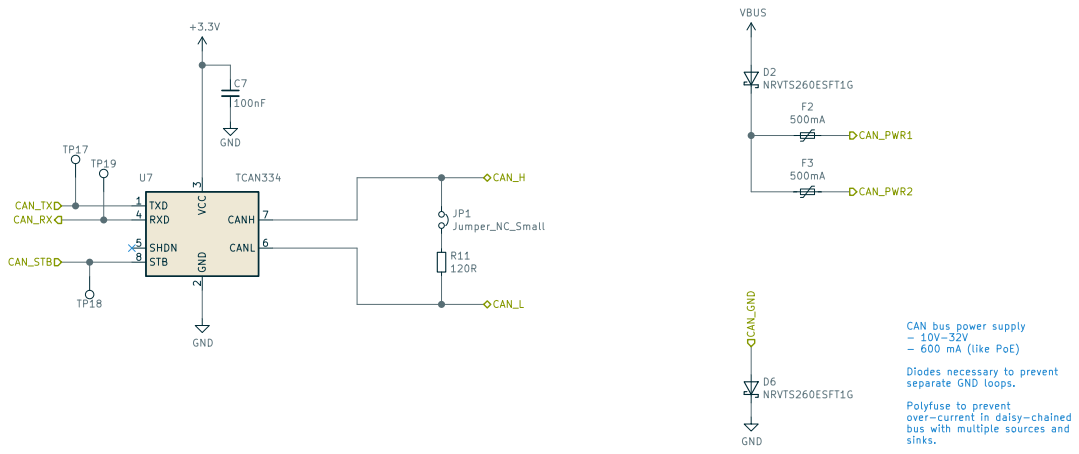
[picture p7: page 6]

3 RXD 4 SHDN 5 CANL 6 CANH 7 STB 8U7 TCAN334 R11

Diodes necessary to prevent
separate GND loops.

Polyfuse to prevent
over-current in daisy-chained
bus with multiple sources and sinks.

File: can.sch Sheet: /CAN/ Copyright © 2020 Libre Solar Technologies GmbH

www.libre.solar

Licensed under CERN-OHL-W version 2 Author: Martin Jäger

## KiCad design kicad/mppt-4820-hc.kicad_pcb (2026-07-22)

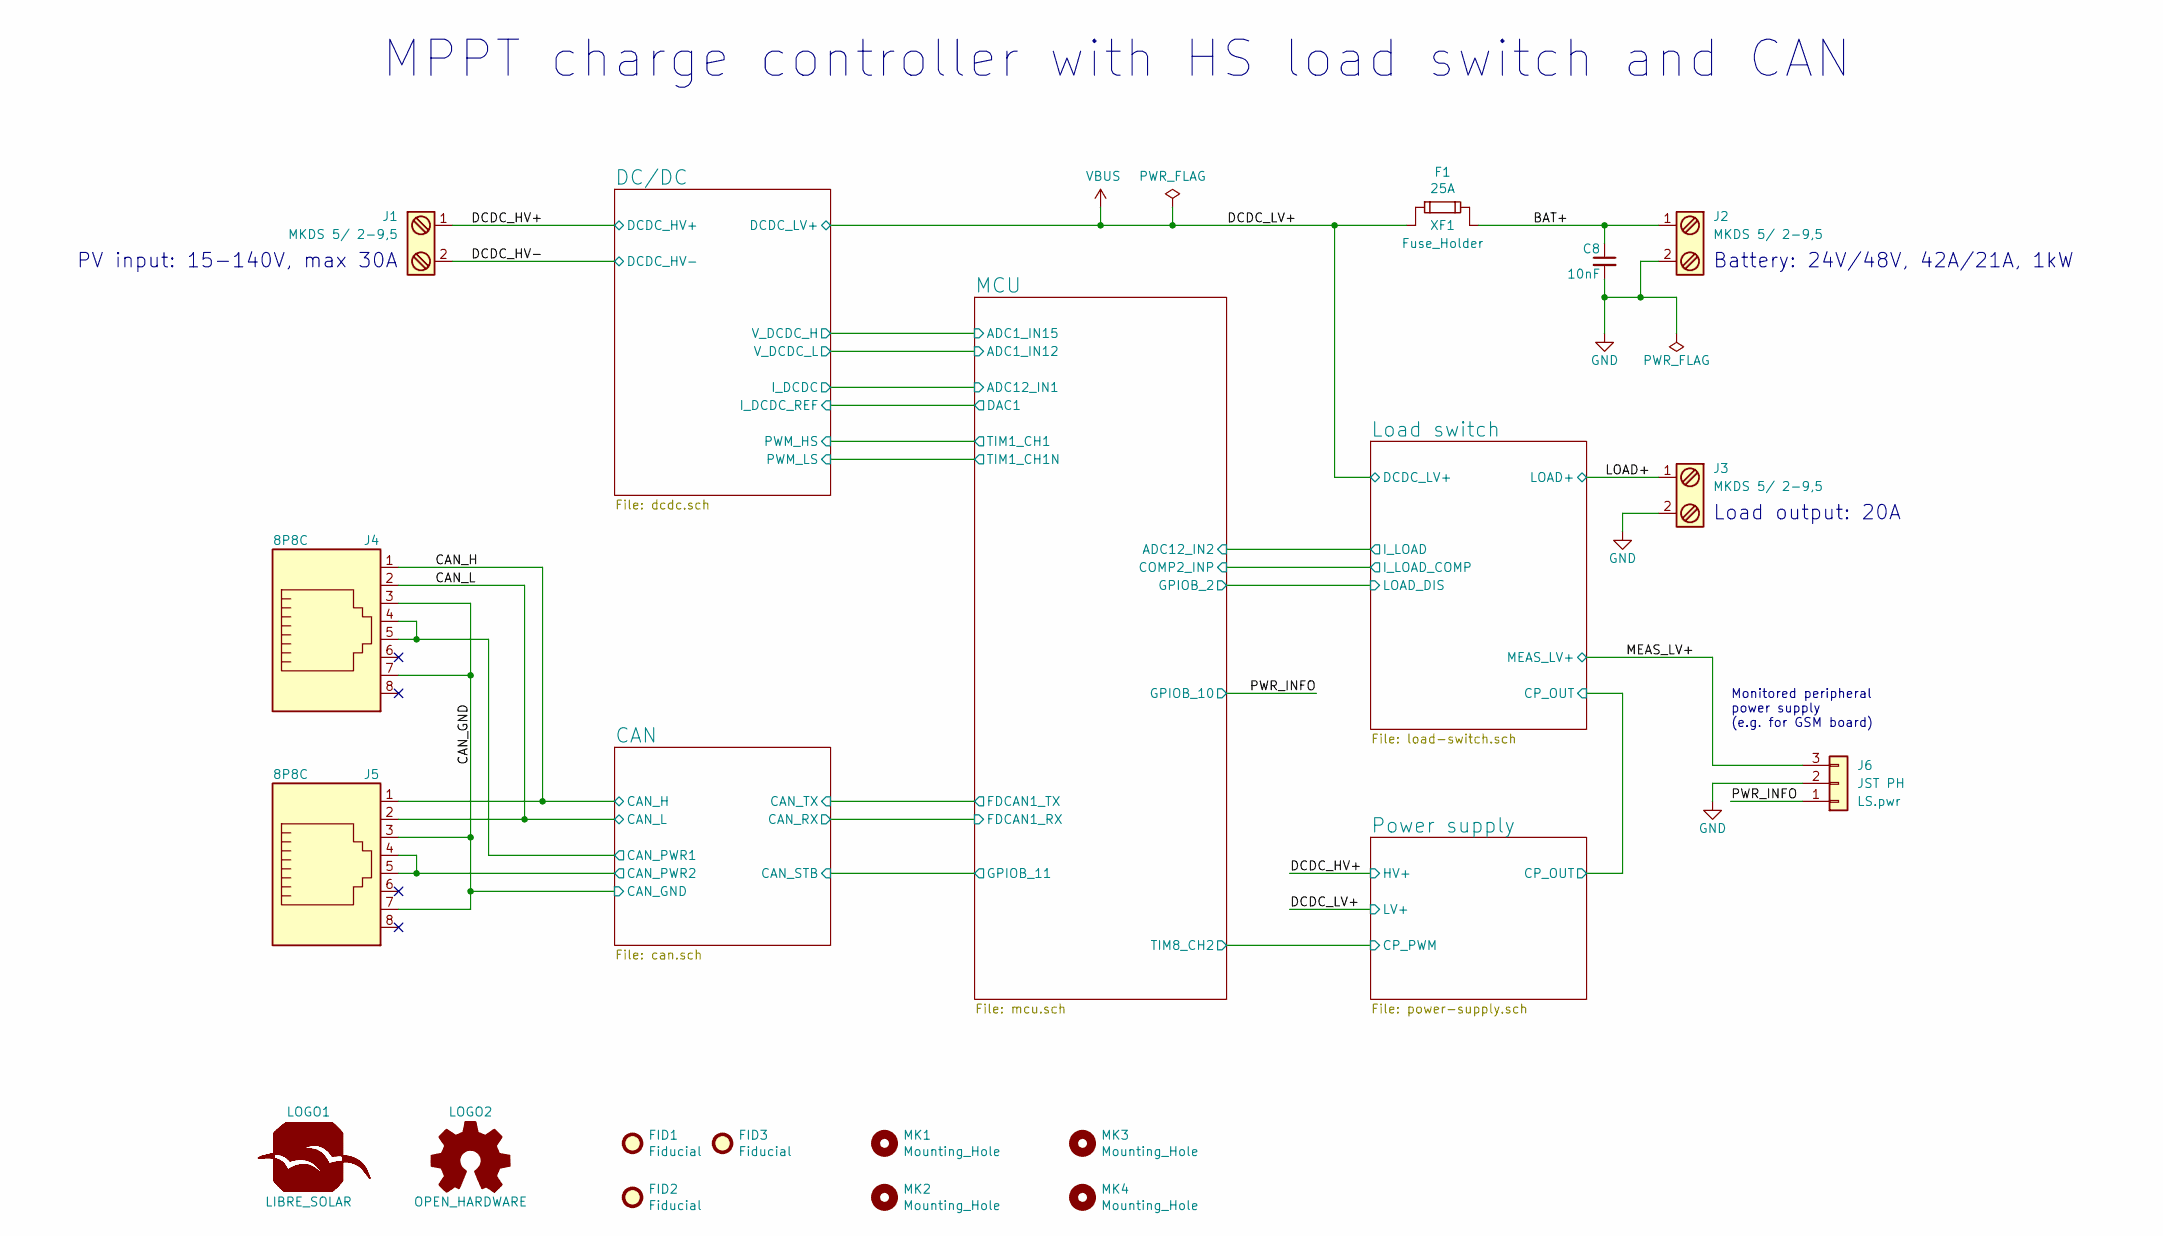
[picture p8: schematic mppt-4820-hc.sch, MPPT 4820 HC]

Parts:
C8: 10nF; C_0603_1608
F1: 25A; NULL; PartNumber 0287025.PXCN
FID1, FID2, FID3: Fiducial; Fiducial_0.7mm
J1, J2, J3: MKDS 5/ 2-9,5; Phoenix_Contact_MKDS_5-2-9,5; PartNumber 1714971
J4, J5: 8P8C; RJ45_8P8C; PartNumber 54602-908LF
J6: JST PH; JST_PH_B3B-PH-K_1x03_P2.00mm_Vertical; PartNumber PH B3B-PH-K 1x3, pitch 2.0mm
LOGO1: LIBRE_SOLAR; LIBRESOLAR_LOGO
LOGO2: OPEN_HARDWARE; OSHW-Logo_5.7x6mm_SilkScreen
MK1, MK2, MK3, MK4: Mounting_Hole; MountingHole_3.2mm_M3
XF1: Fuse_Holder; Keystone-Fuse-3557-2; PartNumber 3557-2

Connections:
/BAT+: C8.1, J2.1, XF1.2
/CAN/CAN_PWR1: J4.4, J4.5; also elsewhere on the board
/CAN/CAN_PWR2: J5.4, J5.5; also elsewhere on the board
/CAN_GND: J4.3, J4.7, J5.3, J5.7; also elsewhere on the board
/CAN_H: J4.1, J5.1; also elsewhere on the board
/DCDC_HV+: J1.1; also elsewhere on the board
/DCDC_HV-: J1.2; also elsewhere on the board
/LOAD+: J3.1; also elsewhere on the board
/MEAS_LV+: J6.3; also elsewhere on the board
/PWR_INFO: J6.1; also elsewhere on the board

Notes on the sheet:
MPPT charge controller with HS load switch and CAN
Monitored peripheral power supply (e.g. for GSM board)
PV input: 15-140V, max 30A
Battery: 24V/48V, 42A/21A, 1kW
Load output: 20A

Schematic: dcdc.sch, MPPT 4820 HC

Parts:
C1: 560µF; CP_Radial_D18.0mm_P7.50mm; PartNumber EKZN201ELL561MJ20S
C2: 100µF; CP_Radial_D18.0mm_P7.50mm; PartNumber UHE2C101MED
C3: 1µF; C_0805_2012
C4: 100nF; C_0805_2012
C5, C27: 680µF; CP_Radial_D18.0mm_P5.00mm_Adapted; PartNumber EEEFK1J681P
C6: 2.2nF; C_0603_1608
C10, C13: 100nF; C_0603_1608
C11, C15: 1nF; C_0603_1608
C12: 2.2µF; C_0603_1608
C14, C16, C17: 10nF; C_0603_1608
C42, C44: 0.22µF; C_Rect_L7.2mm_W3.5mm_P5.00mm_FKS2_FKP2_MKS2_MKP2; PartNumber R463W322050M2M
D7, D14, D15: SS14FL; D_SOD-123; PartNumber SS14FL
D16: 1N4148; D_SOD-123; PartNumber 1N4148W-7-F
L1: 4.7µH; Inductor_4p7uH_HighCurrent_ToroidPad; PartNumber 7443730470
Q1: IPW60R041P6; TO-247-3_Horizontal_BottomHeatsink_Adapted; PartNumber IPW60R041P6
Q2: IPT015N10N5; TO-220-3_Horizontal_BottomHeatsink; PartNumber IPT015N10N5
Q3: IPA045N10N3G; TO-220-3_Horizontal_BottomHeatsink; PartNumber IPA045N10N3G
R1, R2, R3, R5: 3R3; R_0805_2012; PartNumber RC0805FR-073R3L
R4, R12: 4R7; R_1206_3216; PartNumber RC1206FR-074R7L
R6: 1m; R_Bourns_CRE2512; PartNumber CRE2512-FZ-R001E-3
R8, R9: 10R; R_0603_1608
R10: 1k; R_0603_1608
R13: 499k; R_0603_1608; PartNumber RC0603FR-07499KL
R14: 20k; R_0603_1608; PartNumber RC0603FR-0720KL
R17: 169k; R_0603_1608; PartNumber RC0603FR-07169KL
R18: 10k; R_0603_1608; PartNumber RC0603FR-0710KL
R56: 1M; R_0603_1608
RV2: 150V; RV_Disc_D12mm_W4.3mm_P7.5mm; PartNumber V150LA20AP
TP1, TP3, TP5, TP6, TP7, TP8, TP21, TP22: 1.5mm; TestPoint_Pad_D1.5mm
U1: UCC27712; SOIC-8_3.9x4.9mm_Pitch1.27mm; PartNumber UCC27712DR
U3: INA240A3; SOT-363_SC-70-6; PartNumber INA240A3DCNR

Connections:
+3V3: C13.1, U3.3 (V+); also elsewhere on the board
+12V: C12.1, R3.2, U1.1; also elsewhere on the board
/DC/DC/HS_DRV: D14.1 (K), R1.2, U1.7
/DC/DC/LS_DRV: D7.2 (A), D15.1 (K), R2.2, U1.5
/DC/DC/PWM_HS: TP21.1, U1.2; also elsewhere on the board
/DC/DC/PWM_LS: TP22.1, U1.3; also elsewhere on the board
/DC/DC/SHUNT_DCDC_P: C42.1, L1.2, R6.2, R8.1
/DC/DC/SW_NODE: C6.1, C10.2, L1.1, Q1.3 (S), Q2.2 (D), U1.6
/DCDC_HV+: C1.1, C2.1, C3.1, C4.1, C17.1, Q1.2 (D), R13.1, RV2.1, TP7.1; also elsewhere on the board
/DCDC_HV-: C17.2, Q3.2 (D), RV2.2, TP5.1; also elsewhere on the board
/MCU/ADC1_IN12: C16.1, R17.2, R18.1, TP6.1; also elsewhere on the board
/MCU/ADC1_IN15: C14.1, R13.2, R14.1, TP3.1; also elsewhere on the board
/MCU/ADC12_IN1: C15.1, R10.2, TP1.1; also elsewhere on the board
/MCU/DAC1: U3.1 (REF); also elsewhere on the board
unnamed: C6.2, R4.2, R12.2
unnamed: C10.1, R5.2
unnamed: C11.1, R8.2, U3.4 (+)
unnamed: C11.2, R9.2, U3.5 (-)
unnamed: D7.1 (K), Q3.1 (G), R56.1
unnamed: D14.2 (A), Q1.1 (G), R1.1
unnamed: D15.2 (A), Q2.1 (G), R2.1
unnamed: D16.1 (K), R5.1, U1.8
unnamed: D16.2 (A), R3.1
unnamed: R10.1, U3.6

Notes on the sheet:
DC/DC power stage
MOSFET driver
If not stated otherwise, all MLCC 50V X7R
Reverse polarity protection and PV reverse current blocking
Inductor current measurement
Voltage measurement
Inductor L1 (Würth 7443730470): - 4.7µH, 50A saturation, 2.4mΩ DCR - 22.5×22.5×19.5mm radial through-hole - High-side MOSFET Q1: IPW60R041P6 (650V, 38A, 41mΩ, TO-247) - Low-side MOSFET Q2: IPT015N10N5 (100V, 100A, 1.5mΩ, TO-220) - Gate driver U1: UCC27712 half-bridge, 150V bootstrap; 500ns dead-tim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

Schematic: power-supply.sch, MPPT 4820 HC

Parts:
C18: 1µF; C_0805_2012
C19: 4.7µF; C_1210_3225; PartNumber GRJ32DC72A475KE11L
C20, C24: 100nF; C_0603_1608
C21, C23: 10µF; C_0805_2012; PartNumber GRM21BR61E106KA73L
C25: 10nF; C_0603_1608
C40: 1µF; C_0603_1608; PartNumber CC0805KKX7R9BB105
C41: 4.7µF; C_0603_1608; PartNumber 885012107018
D1: SS16FP; D_PowerDI-123; PartNumber SS16FP
D4: BAS70-04; SOT-23; PartNumber BAS70-04LT1G
D5: 12V; D_SOT-23_ANK; PartNumber SZBZX84C12LT3G
D9: 47V; D_SOT-23_ANK; PartNumber SZBZX84C47LT1G
D10: 1N4148; D_SOD-123; PartNumber 1N4148W-7-F
L2: 4.7µH; L_0805_2012Metric; PartNumber LQM21PN4R7NGRD
L3: 47µH; Bourns_SRN6045TA; PartNumber NR6045T470M
Q4: BUK98180-100A; SOT-223-3_TabPin2; PartNumber BUK98180-100A/CUX
R16, R19, R24, R64: 10k; R_0603_1608
R22, R60, R65: 100k; R_0603_1608
R23: 33k; R_0603_1608
R25, R66: 1k; R_0603_1608
T1, T2, T3, T10: BC846B; SOT-23; PartNumber BC846BLT1G
T4: BC856B; SOT-23; PartNumber BC856BLT1G
TP4, TP9, TP10, TP11: 1.5mm; TestPoint_Pad_D1.5mm
U4: LMR16030X; SOT-23-6; PartNumber LMR16030XDDCR

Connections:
+3V3: C21.1, C23.1, L3.2, R23.1, TP11.1; also elsewhere on the board
+12V: C41.1, D4.1, T10.2 (E), TP4.1; also elsewhere on the board
/DCDC_HV+: Q4.2 (D), R60.2; also elsewhere on the board
/Load switch/CP_OUT: C24.1, D4.2, R65.2, TP10.1; also elsewhere on the board
/Power supply/CP_PWM: R16.2; also elsewhere on the board
/Power supply/CP_SW: C25.2, T3.2 (E), T4.2 (E)
/Power supply/SUPPLY_INPUT: C18.1, C40.1, D10.1 (K), L2.1, Q4.3 (S), R64.2, T10.3 (C), TP9.1
unnamed: C19.1, L2.2, U4.4, U4.5
unnamed: C20.1, U4.1
unnamed: C20.2, D1.1 (K), L3.1, U4.6
unnamed: C25.1, D4.3
unnamed: D5.1 (K), R64.1, T10.1 (B)
unnamed: D9.1 (K), Q4.1 (G), R60.1, R66.2
unnamed: R16.1, T1.1 (B)
unnamed: R19.2, R65.1, T2.1 (B)
unnamed: R22.1, R25.1, T1.3 (C)
unnamed: R23.2, R24.1, U4.3
unnamed: R25.2, T3.1 (B), T4.1 (B)
unnamed: R66.1, T2.3 (C)

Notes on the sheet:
HV/LV side to 3.3V (SMPS)
If not stated otherwise, all MLCC 50V X7R
12V MOSFET driver supply voltage (emitter follower)
Some applications (e.g. Li-ion batteries) require an internal power supply from the high voltage side (e.g. solar panel input). The source follower with Q4 limits the supply input below 60V. T2 selects LV+ as supply to increase efficiency as soon as the charge pump is on.
Charge pump
Supply rail selection

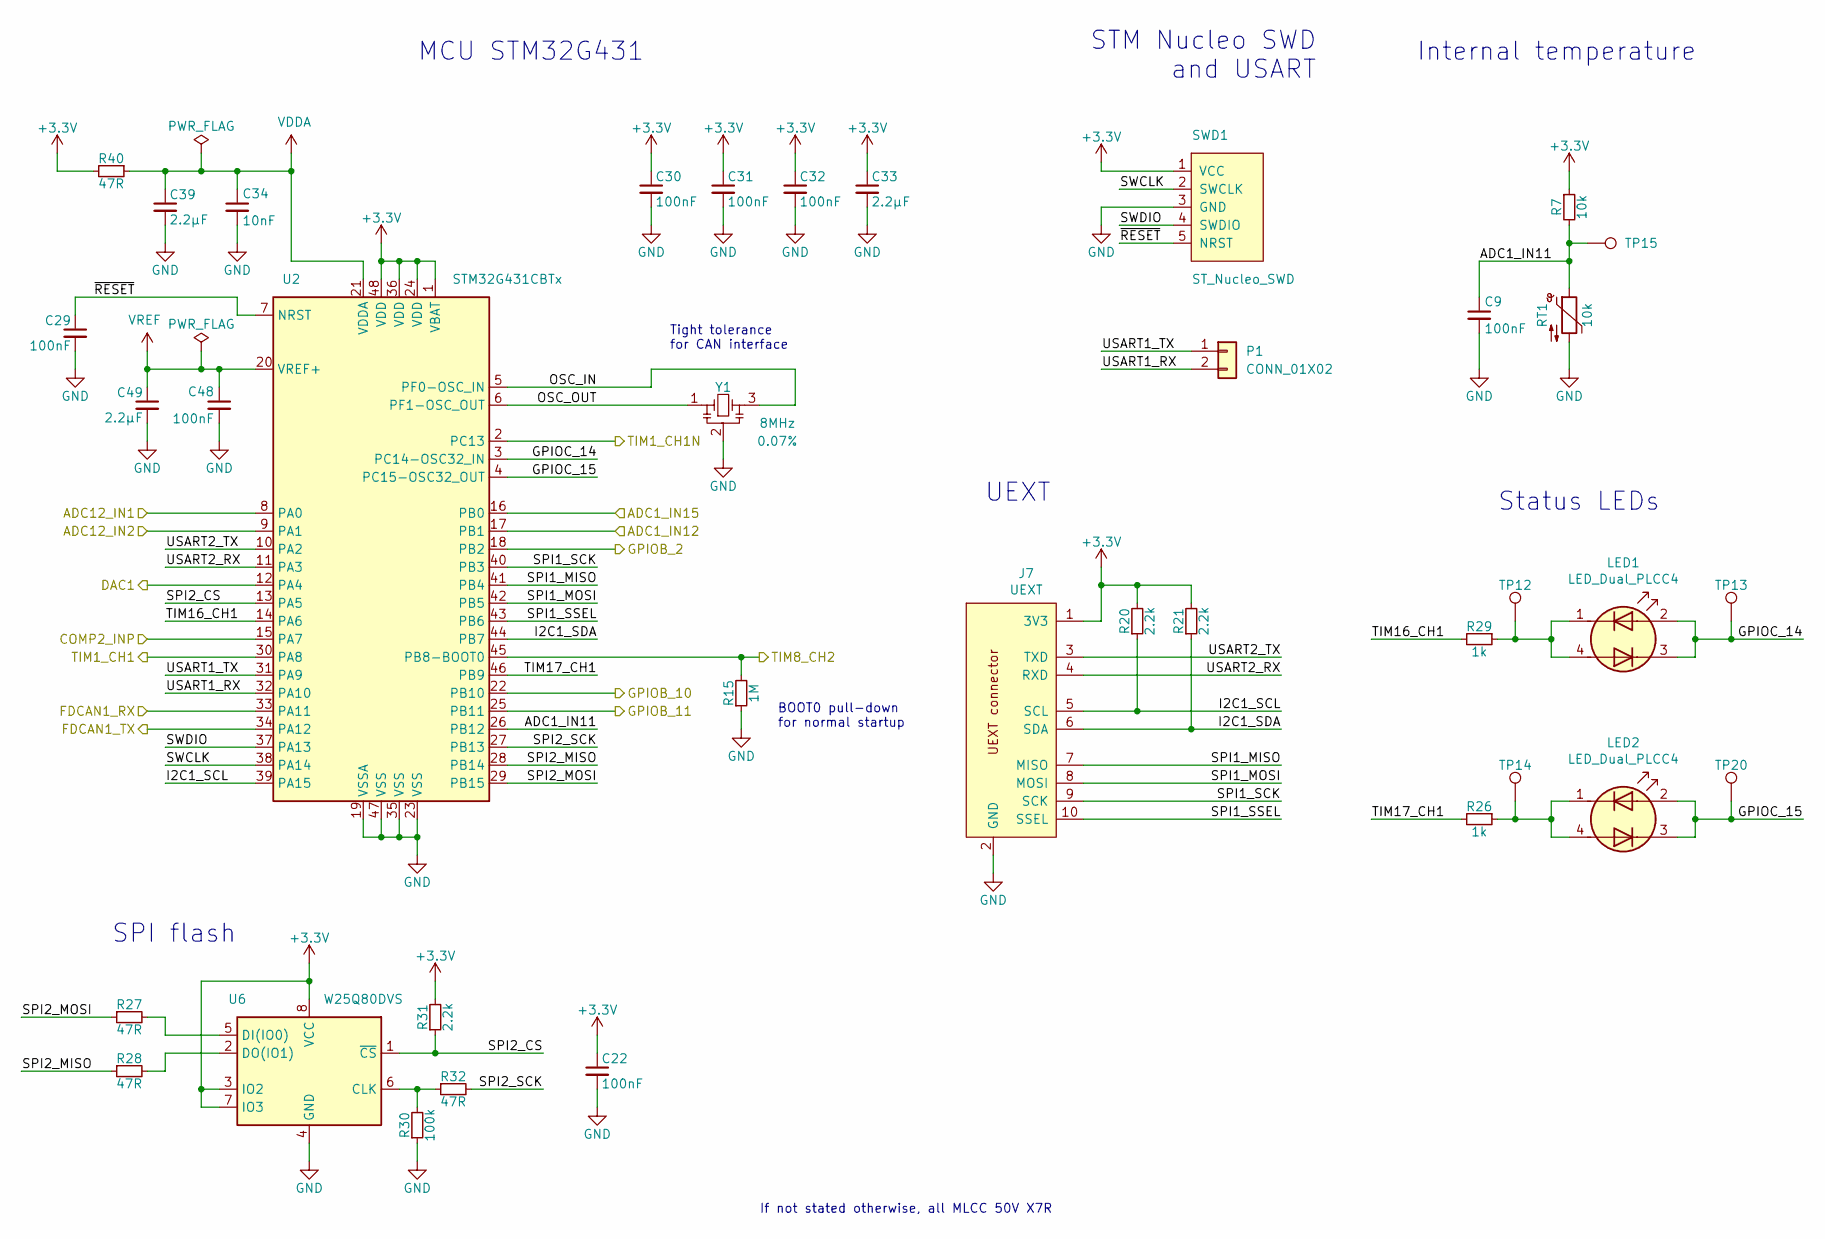
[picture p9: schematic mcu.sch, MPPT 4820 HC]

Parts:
C9, C22, C29, C30, C31, C32, C48: 100nF; C_0603_1608
C33, C39, C49: 2.2µF; C_0603_1608
C34: 10nF; C_0603_1608
J7: UEXT; Box_Header_2x05x2.54mm_Straight; PartNumber Box header 2x5, 2.54mm pitch
LED1, LED2: LED_Dual_PLCC4; LED_Avago_PLCC4_3.2x2.8mm_CW; PartNumber LTST-E682KRKGWT
P1: CONN_01X02; PinHeader_1x02_P2.54mm_Vertical; PartNumber Pin header 1x5, 2.54mm pitch
R7: 10k; R_0603_1608
R15: 1M; R_0603_1608
R20, R21, R31: 2.2k; R_0603_1608
R26, R29: 1k; R_0603_1608
R27, R28, R32, R40: 47R; R_0603_1608
R30: 100k; R_0603_1608
RT1: 10k; C_Disc_D3.8mm_W2.6mm_P2.50mm; PartNumber NTCG163JF103FT1S
SWD1: ST_Nucleo_SWD; PinHeader_1x05_P2.54mm_Vertical; PartNumber Pin header 1x5, 2.54mm pitch
TP12, TP13, TP14, TP15, TP20: 1.5mm; TestPoint_Pad_D1.5mm
U2: STM32G431CBTx; LQFP-48_7x7mm_P0.5mm; PartNumber STM32G431CBT6
U6: W25Q80DVS; SOIC-8_3.9x4.9mm_Pitch1.27mm; PartNumber W25Q80DVSNIG
Y1: 8MHz; Resonator_Murata_CSTNE; PartNumber CSTNE8M00GH5C000R0

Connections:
+3V3: C22.1, C30.1, C31.1, C32.1, C33.1, J7.1 (3V3), R7.1, R20.2, R21.2, R31.2, R40.2, SWD1.1 (VCC), U2.1 (VBAT), U2.24 (VDD), U2.36 (VDD), U2.48 (VDD), U6.3 (IO2), U6.7 (IO3), U6.8 (VCC); also elsewhere on the board
/CAN/CAN_STB: U2.25 (PB11); also elsewhere on the board
/DC/DC/PWM_HS: U2.30 (PA8); also elsewhere on the board
/DC/DC/PWM_LS: U2.2 (PC13); also elsewhere on the board
/MCU/ADC1_IN11: C9.1, R7.2, RT1.1, TP15.1, U2.26 (PB12)
/MCU/ADC1_IN12: U2.17 (PB1); also elsewhere on the board
/MCU/ADC1_IN15: U2.16 (PB0); also elsewhere on the board
/MCU/ADC12_IN1: U2.8 (PA0); also elsewhere on the board
/MCU/ADC12_IN2: U2.9 (PA1); also elsewhere on the board
/MCU/COMP2_INP: U2.15 (PA7); also elsewhere on the board
/MCU/DAC1: U2.12 (PA4); also elsewhere on the board
/MCU/GPIOB_2: U2.18 (PB2); also elsewhere on the board
/MCU/GPIOC_14: LED1.2 (K1), LED1.3 (A2), TP13.1, U2.3 (PC14-OSC32_IN)
/MCU/GPIOC_15: LED2.2 (K1), LED2.3 (A2), TP20.1, U2.4 (PC15-OSC32_OUT)
/MCU/I2C1_SCL: J7.5 (SCL), R20.1, U2.39 (PA15)
/MCU/I2C1_SDA: J7.6 (SDA), R21.1, U2.44 (PB7)
/MCU/OSC_IN: U2.5 (PF0-OSC_IN), Y1.3
/MCU/OSC_OUT: U2.6 (PF1-OSC_OUT), Y1.1
/MCU/SPI1_MISO: J7.7 (MISO), U2.41 (PB4)
/MCU/SPI1_MOSI: J7.8 (MOSI), U2.42 (PB5)
/MCU/SPI1_SCK: J7.9 (SCK), U2.40 (PB3)
/MCU/SPI1_SSEL: J7.10 (SSEL), U2.43 (PB6)
/MCU/SPI2_CS: R31.1, U2.13 (PA5), U6.1 (~CS)
/MCU/SPI2_MISO: R28.1, U2.28 (PB14)
/MCU/SPI2_MOSI: R27.1, U2.29 (PB15)
/MCU/SPI2_SCK: R32.2, U2.27 (PB13)
/MCU/SWCLK: SWD1.2 (SWCLK), U2.38 (PA14)
/MCU/SWDIO: SWD1.4 (SWDIO), U2.37 (PA13)
/MCU/TIM16_CH1: R29.2, U2.14 (PA6)
/MCU/TIM17_CH1: R26.2, U2.46 (PB9)
/MCU/USART1_RX: P1.2, U2.32 (PA10)
/MCU/USART1_TX: P1.1, U2.31 (PA9)
/MCU/USART2_RX: J7.4 (RXD), U2.11 (PA3)
/MCU/USART2_TX: J7.3 (TXD), U2.10 (PA2)
/MCU/~RESET: C29.1, SWD1.5 (NRST), U2.7 (NRST)
/PWR_INFO: U2.22 (PB10); also elsewhere on the board
/Power supply/CP_PWM: R15.2, U2.45 (PB8-BOOT0); also elsewhere on the board
unnamed: LED1.1 (A1), LED1.4 (K2), R29.1, TP12.1
unnamed: LED2.1 (A1), LED2.4 (K2), R26.1, TP14.1
unnamed: R27.2, U6.5 (DI(IO0))
unnamed: R28.2, U6.2 (DO(IO1))
unnamed: R30.2, R32.1, U6.6 (CLK)
VDDA: C34.1, C39.1, R40.1, U2.21 (VDDA)
VREF: C48.1, C49.1, U2.20 (VREF+)

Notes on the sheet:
Status LEDs
MCU STM32G431
STM Nucleo SWD and USART
Tight tolerance for CAN interface
SPI flash
If not stated otherwise, all MLCC 50V X7R
Internal temperature
UEXT
BOOT0 pull-down for normal startup

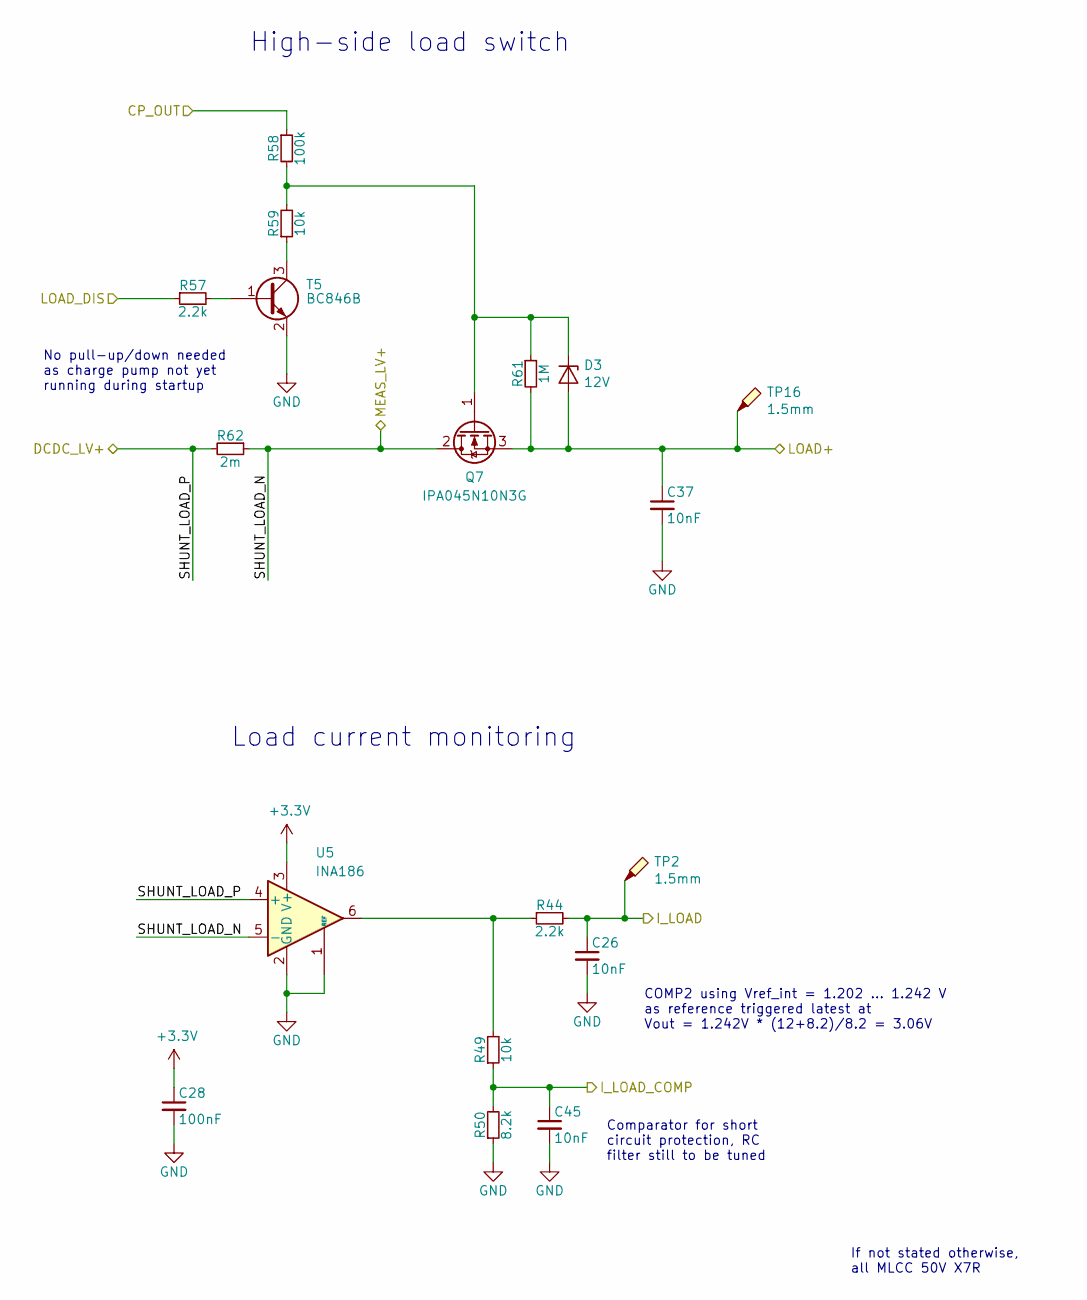
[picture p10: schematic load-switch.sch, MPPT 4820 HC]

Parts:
C26, C37, C45: 10nF; C_0603_1608
C28: 100nF; C_0603_1608
D3: 12V; D_SOT-23_ANK; PartNumber SZBZX84C12LT3G
Q7: IPA045N10N3G; TO-220-3_Horizontal_BottomHeatsink; PartNumber IPA045N10N3G
R44, R57: 2.2k; R_0603_1608
R49, R59: 10k; R_0603_1608
R50: 8.2k; C_0603_1608
R58: 100k; R_0603_1608
R61: 1M; R_0603_1608
R62: 2m; R_Bourns_CRE2512; PartNumber CRE2512-FZ-R002E-3
T5: BC846B; SOT-23; PartNumber BC846BLT1G
TP2, TP16: 1.5mm; TestPoint_Pad_D1.5mm
U5: INA186; SOT-363_SC-70-6; PartNumber INA186A1IDCKR

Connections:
+3V3: C28.1, U5.3 (VCC); also elsewhere on the board
/LOAD+: C37.1, D3.2 (A), Q7.3 (S), R61.2, TP16.1; also elsewhere on the board
/Load switch/CP_OUT: R58.1; also elsewhere on the board
/MCU/ADC12_IN2: C26.1, R44.2, TP2.1; also elsewhere on the board
/MCU/COMP2_INP: C45.1, R49.1, R50.2; also elsewhere on the board
/MCU/GPIOB_2: R57.1; also elsewhere on the board
/MEAS_LV+: Q7.2 (D), R62.1, U5.5 (SHDN); also elsewhere on the board
unnamed: D3.1 (K), Q7.1 (G), R58.2, R59.2, R61.1
unnamed: R57.2, T5.1 (B)
unnamed: R59.1, T5.3 (C)

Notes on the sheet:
No pull-up/down needed as charge pump not yet running during startup
If not stated otherwise, all MLCC 50V X7R
Load current monitoring
Comparator for short circuit protection, RC filter still to be tuned
COMP2 using Vref_int = 1.202 ... 1.242 V as reference triggered latest at Vout = 1.242V * (12+8.2)/8.2 = 3.06V
High-side load switch

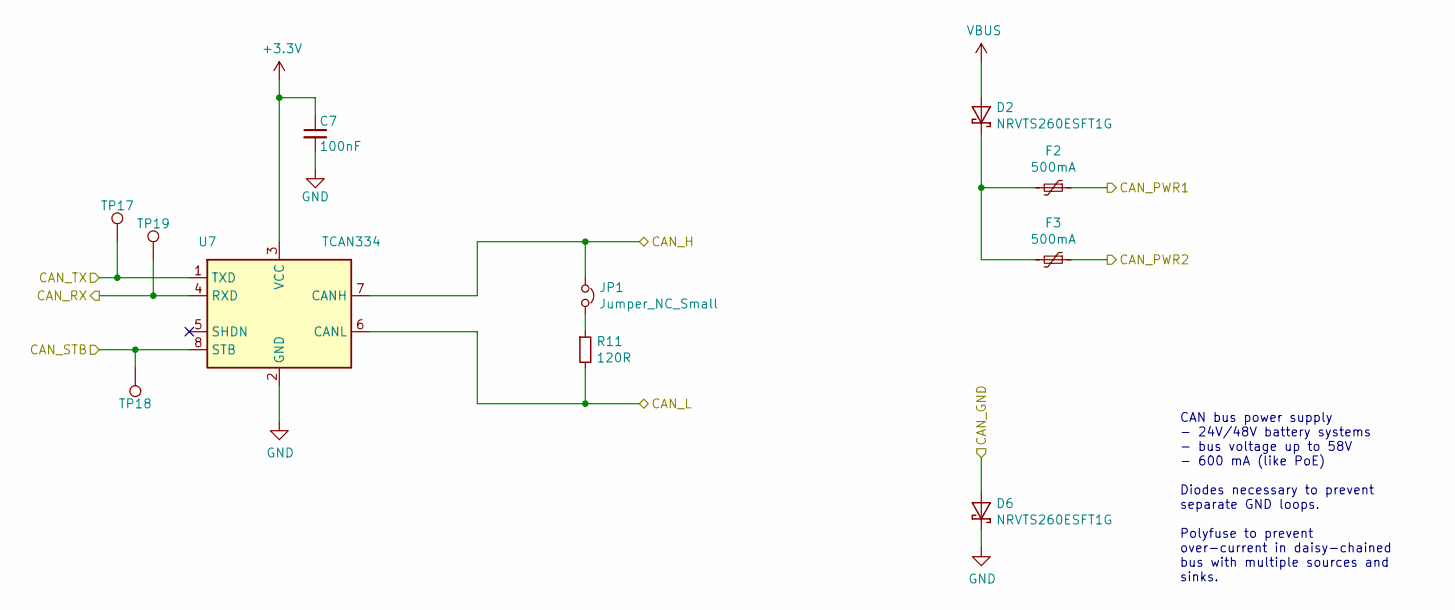
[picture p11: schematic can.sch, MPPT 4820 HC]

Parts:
C7: 100nF; C_0603_1608
D2, D6: NRVTS260ESFT1G; D_SOD-123; PartNumber NRVTS260ESFT1G
F2, F3: 500mA; Fuse_1206_3216Metric; PartNumber 0ZCJ0050AF2E
JP1: Jumper_NC_Small; PinHeader_1x02_P2.54mm_Vertical
R11: 120R; R_1206_3216
TP17, TP18, TP19: 1.5mm; TestPoint_Pad_D1.5mm
U5: TCAN334; SOIC-8_3.9x4.9mm_Pitch1.27mm; PartNumber TCAN334DR

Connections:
+3V3: C7.1, U5.3 (VCC); also elsewhere on the board
/CAN/CAN_PWR1: F2.1; also elsewhere on the board
/CAN/CAN_PWR2: F3.1; also elsewhere on the board
/CAN/CAN_STB: TP18.1, U5.8 (STB); also elsewhere on the board
/CAN_GND: D6.2 (A); also elsewhere on the board
/CAN_H: JP1.1, U5.7 (CANH); also elsewhere on the board
/MEAS_LV+: U5.5 (SHDN); also elsewhere on the board
unnamed: D2.1 (K), F2.2, F3.2
unnamed: JP1.2, R11.1

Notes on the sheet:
CAN bus power supply - 24V/48V battery systems - bus voltage up to 58V - 600 mA (like PoE) Diodes necessary to prevent separate GND loops. Polyfuse to prevent over-current in daisy-chained bus with multiple sources and sinks.

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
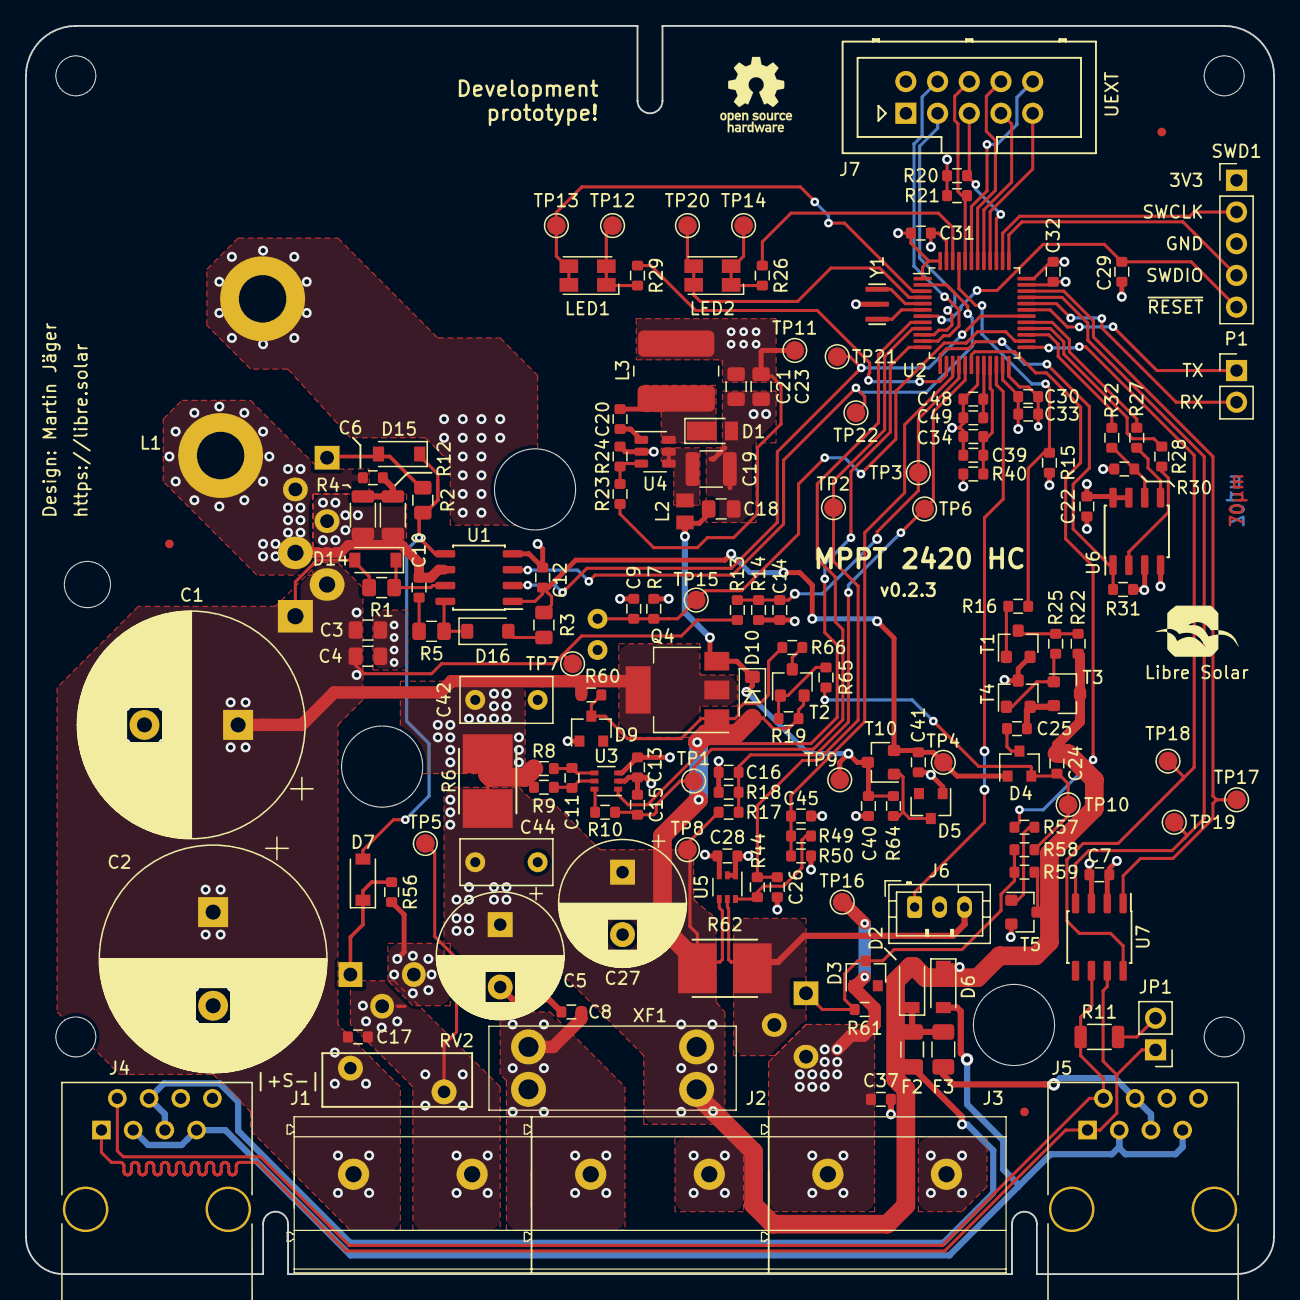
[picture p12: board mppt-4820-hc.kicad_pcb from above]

Board: 4 copper layers, 100.0 x 100.0 mm, 172 parts (0 on the bottom side), 94 nets.

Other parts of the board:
U7: TCAN334; SOIC-8_3.9x4.9mm_Pitch1.27mm

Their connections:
+3V3: U7.3; also elsewhere on the board
/CAN/CAN_STB: U7.8; also elsewhere on the board
/CAN_H: U7.7; also elsewhere on the board

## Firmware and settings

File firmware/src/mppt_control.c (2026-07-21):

/*
 * MPPT Control Loop for MPPT-4820-HC
 * 24V/48V (1kW class) MPPT Charge Controller
 *
 * Integrates synchronous buck converter control with the MPPT algorithm.
 * Firmware companion to LibreSolar/charge-controller-firmware.
 */

#include "dcdc_sync.h"
#include "adc_scaling.h"

/* System state definitions */
typedef enum {
    STATE_IDLE,
    STATE_MPPT,
    STATE_CV,
    STATE_FAULT
} mppt_state_t;

/* Shared ADC results (populated by ADC interrupt handler) */
float v_solar   = 0.0f;
float v_battery = 0.0f;
float i_solar   = 0.0f;

static mppt_state_t system_state = STATE_IDLE;
static float mppt_duty   = PWM_DUTY_MIN;
static float prev_power  = 0.0f;
static float prev_duty   = 0.0f;
static const float step  = 0.001f;

/**
 * @brief  Initialize the MPPT charge controller.
 *         Call once at startup before entering the main control loop.
 */
void mppt_init(void)
{
    /* Initialize synchronous buck converter (TIM1 complementary PWM) */
    dcdc_sync_init();

    /* Reset control state */
    mppt_duty  = PWM_DUTY_MIN;
    prev_power = 0.0f;
    prev_duty  = 0.0f;

    system_state = STATE_MPPT;
}

/**
 * @brief  Main MPPT control loop iteration.
 *         Call periodically from a timer interrupt or RTOS task (e.g. 10ms).
 */
void mppt_control_loop(void)
{
    /* Check for hardware converter faults (shoot-through protection) */
    if (dcdc_check_fault()) {
        system_state = STATE_FAULT;
        return;
    }

    if (system_state == STATE_FAULT) {
        return;
    }

    /*
     * Perturb-and-observe MPPT algorithm.
     * The duty cycle is adjusted in small steps to track the maximum power
     * point of the solar panel.
     */
    float power = v_solar * i_solar;

    if (power > prev_power) {
        /* Moving toward MPP – continue in the same direction */
        if (mppt_duty >= prev_duty) {
            mppt_duty += step;
        } else {
            mppt_duty -= step;
        }
    } else {
        /* Moving away from MPP – reverse direction */
        if (mppt_duty >= prev_duty) {
            mppt_duty -= step;
        } else {
            mppt_duty += step;
        }
    }

    prev_power = power;
    prev_duty  = mppt_duty;

    /* Apply updated duty cycle to the synchronous converter */
    dcdc_set_duty_cycle(mppt_duty);
}

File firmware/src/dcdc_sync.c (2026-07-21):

/*
 * Synchronous Buck Converter Implementation for MPPT-4820-HC
 *
 * Configures STM32G4 TIM1 for complementary PWM with hardware dead-time
 * to drive the UCC27712 half-bridge gate driver.
 *
 * High-side:  TIM1_CH1  → UCC27712 HIN → Q1 (IPW60R041P6)
 * Low-side:   TIM1_CH1N → UCC27712 LIN → Q2 (IPT015N10N5)
 */

#include "dcdc_sync.h"
#include "stm32g4xx_hal.h"
#include <math.h>

/* Private variables */
static TIM_HandleTypeDef htim1;
static bool fault_detected = false;

/**
 * @brief  Initialize synchronous buck converter.
 *         Configures TIM1 for complementary PWM with hardware dead-time.
 */
void dcdc_sync_init(void)
{
    /* Enable TIM1 clock */
    __HAL_RCC_TIM1_CLK_ENABLE();

    /* Calculate timer parameters (170MHz system clock assumed) */
    uint32_t timer_clock = HAL_RCC_GetPCLK2Freq() * 2;
    uint32_t period = (timer_clock / PWM_FREQUENCY) - 1;

    /* Dead-time counts: PWM_DEAD_TIME_NS at timer_clock Hz.
     * Reorder to avoid overflow: (timer_clock / 1000000U) gives MHz, then × ns / 1000. */
    uint32_t dead_time_counts = (timer_clock / 1000000U) * PWM_DEAD_TIME_NS / 1000U;

    htim1.Instance               = TIM1;
    htim1.Init.Prescaler         = 0;
    htim1.Init.CounterMode       = TIM_COUNTERMODE_UP;
    htim1.Init.Period            = period;
    htim1.Init.ClockDivision     = TIM_CLOCKDIVISION_DIV1;
    htim1.Init.RepetitionCounter = 0;
    htim1.Init.AutoReloadPreload = TIM_AUTORELOAD_PRELOAD_ENABLE;

    HAL_TIM_PWM_Init(&htim1);

    /* Configure PWM channel 1 for complementary output */
    TIM_OC_InitTypeDef sConfigOC = {0};
    sConfigOC.OCMode       = TIM_OCMODE_PWM1;
    sConfigOC.Pulse        = 0;
    sConfigOC.OCPolarity   = TIM_OCPOLARITY_HIGH;
    sConfigOC.OCNPolarity  = TIM_OCNPOLARITY_HIGH;
    sConfigOC.OCFastMode   = TIM_OCFAST_DISABLE;
    sConfigOC.OCIdleState  = TIM_OCIDLESTATE_RESET;
    sConfigOC.OCNIdleState = TIM_OCNIDLESTATE_RESET;

    HAL_TIM_PWM_ConfigChannel(&htim1, &sConfigOC, TIM_CHANNEL_1);

    /* Configure break and dead-time */
    TIM_BreakDeadTimeConfigTypeDef sBreakDeadTimeConfig = {0};
    sBreakDeadTimeConfig.OffStateRunMode  = TIM_OSSR_ENABLE;
    sBreakDeadTimeConfig.OffStateIDLEMode = TIM_OSSI_ENABLE;
    sBreakDeadTimeConfig.LockLevel        = TIM_LOCKLEVEL_OFF;
    sBreakDeadTimeConfig.DeadTime         = (uint8_t)(dead_time_counts & 0xFFU);
    sBreakDeadTimeConfig.BreakState       = TIM_BREAK_ENABLE;
    sBreakDeadTimeConfig.BreakPolarity    = TIM_BREAKPOLARITY_HIGH;
    sBreakDeadTimeConfig.BreakFilter      = 0;
    sBreakDeadTimeConfig.AutomaticOutput  = TIM_AUTOMATICOUTPUT_DISABLE;

    HAL_TIMEx_ConfigBreakDeadTime(&htim1, &sBreakDeadTimeConfig);

    /* Start complementary PWM on CH1 / CH1N */
    HAL_TIM_PWM_Start(&htim1, TIM_CHANNEL_1);
    HAL_TIMEx_PWMN_Start(&htim1, TIM_CHANNEL_1);

    fault_detected = false;
}

/**
 * @brief  Set PWM duty cycle.
 * @param  duty  Duty cycle in range [0.0, 1.0].
 *               Applied simultaneously to high-side (CH1) and complementary
 *               low-side (CH1N) with hardware-enforced dead-time.
 */
void dcdc_set_duty_cycle(float duty)
{
    if (duty > PWM_DUTY_MAX) {
        duty = PWM_DUTY_MAX;
    }
    if (duty < PWM_DUTY_MIN) {
        duty = PWM_DUTY_MIN;
    }

    if (fault_detected) {
        duty = 0.0f;
    }

    uint32_t pulse = (uint32_t)(duty * (float)(htim1.Init.Period + 1U));
    __HAL_TIM_SET_COMPARE(&htim1, TIM_CHANNEL_1, pulse);
}

/**
 * @brief  Emergency stop – disable all PWM outputs immediately.
 */
void dcdc_emergency_stop(void)
{
    __HAL_TIM_MOE_DISABLE(&htim1);
    __HAL_TIM_SET_COMPARE(&htim1, TIM_CHANNEL_1, 0);
    fault_detected = true;
}

/**
 * @brief  Check for shoot-through or other hardware faults.
 * @return true if a fault is active, false otherwise.
 */
bool dcdc_check_fault(void)
{
    /* Hardware break flag indicates shoot-through protection triggered */
    if (__HAL_TIM_GET_FLAG(&htim1, TIM_FLAG_BREAK) != RESET) {
        __HAL_TIM_CLEAR_FLAG(&htim1, TIM_FLAG_BREAK);
        dcdc_emergency_stop();
        return true;
    }

    return fault_detected;
}

/**
 * @brief  Detect discontinuous conduction mode (DCM).
 *         Used to optimize light-load efficiency by skipping low-side pulses.
 * @return true if operating in DCM, false if CCM.
 */
bool is_dcm_mode(void)
{
    extern float i_solar;
    extern float v_solar;
    extern float v_battery;

    float duty = (float)__HAL_TIM_GET_COMPARE(&htim1, TIM_CHANNEL_1) /
                 (float)(htim1.Init.Period + 1U);

    /* ΔI_L = (V_in − V_out) × D / (L × f_sw) */
    const float L   = 4.7e-6f;  /* Matches dcdc.sch L1 (Würth 7443730470, 4.7µH) */
    const float f_sw = (float)PWM_FREQUENCY;
    float i_ripple  = (v_solar - v_battery) * duty / (L * f_sw);

    /* DCM when average current is less than half the ripple */
    return (fabsf(i_solar) < (i_ripple / 2.0f));
}

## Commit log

2026-02-20 Upgrade to MPPT-4820-HC: 48V/20A synchronous buck converter design
    [dcdc.sch]
2026-02-20 Update all references from MPPT 2420 HC to MPPT 4820 HC
    [can.sch, load-switch.sch, mcu.sch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]
2026-02-23 Implement 1kW hardware upgrade: update component values in KiCad schematics and firmware constants
    [dcdc.sch, mppt-4820-hc.sch, power-supply.sch]
2026-07-21 Align docs and firmware with 24V/48V baseline
    [can.sch, mppt-4820-hc_bom_(hv_supply,can).csv]
2026-07-21 Address review follow-ups and portability issues
    [can.sch]
2026-07-21 Resolve validation follow-ups on timing and schematic linkage
    [dcdc.sch]
2026-07-22 Sync KiCad PCB to updated power stage
    [dcdc.sch, mppt-4820-hc.kicad_pcb]
2026-07-22 Fix PCB net width targeting
    [mppt-4820-hc.kicad_pcb]
